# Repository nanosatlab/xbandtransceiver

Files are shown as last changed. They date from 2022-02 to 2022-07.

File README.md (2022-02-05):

# **Description**

The subsystem is designed as a generic X-band front-end subsystem. It will have to communicate with an On-Board-Computer (OBC) using UART protocol, be powered from the spacecraft’s 12 V power bus and have a PC/104 daughter board form factor. It also has to ensure a downlink data rate of at least 10 Mbps from 5º over the horizon at a 550 km LEO orbit, and with a bit-error-rate (BER) of 10^-5.

The subsystem is formed by:	SDR <-> Front-End <-> Antenna

The objective of this repository is to make accessible all the files related to the X-band transceiver, also called XCOMMS, which includes the hardware designs and all the necessary software of the subsystem as well as the different test boards that have been developed. This repository also includes the design of the required evaluatino boards that have been required for testing the subsystem.

# **Current state of the project**

At the moment, none of the PCB designs have been updated because they are pending to be translated from Altium to KiCad.
The project just includes the Front-End part.
The SDR and antenna parts are TBD. 

# **Project Tree Structure**

	XCOMMS
	├───Readme
	├───FrontEnd
	│   ├───Readme
	│   ├───HW
	│   │   ├───KiCad_Libraries
	│   │   ├───XCOMMS_Interface
	│   │   └───XCOMMS_RF
	│   └───SW
 	│	
	└───TesBoards
	    ├───PA_HMC952ALP5GE
	    │   ├───HW
	    │   └───SW
	    └───PLL_LMX2572
	    	├───Readme
		├───HW
		└───SW
		    ├───LMX2572
		    └───LMX2572_TICSPRO

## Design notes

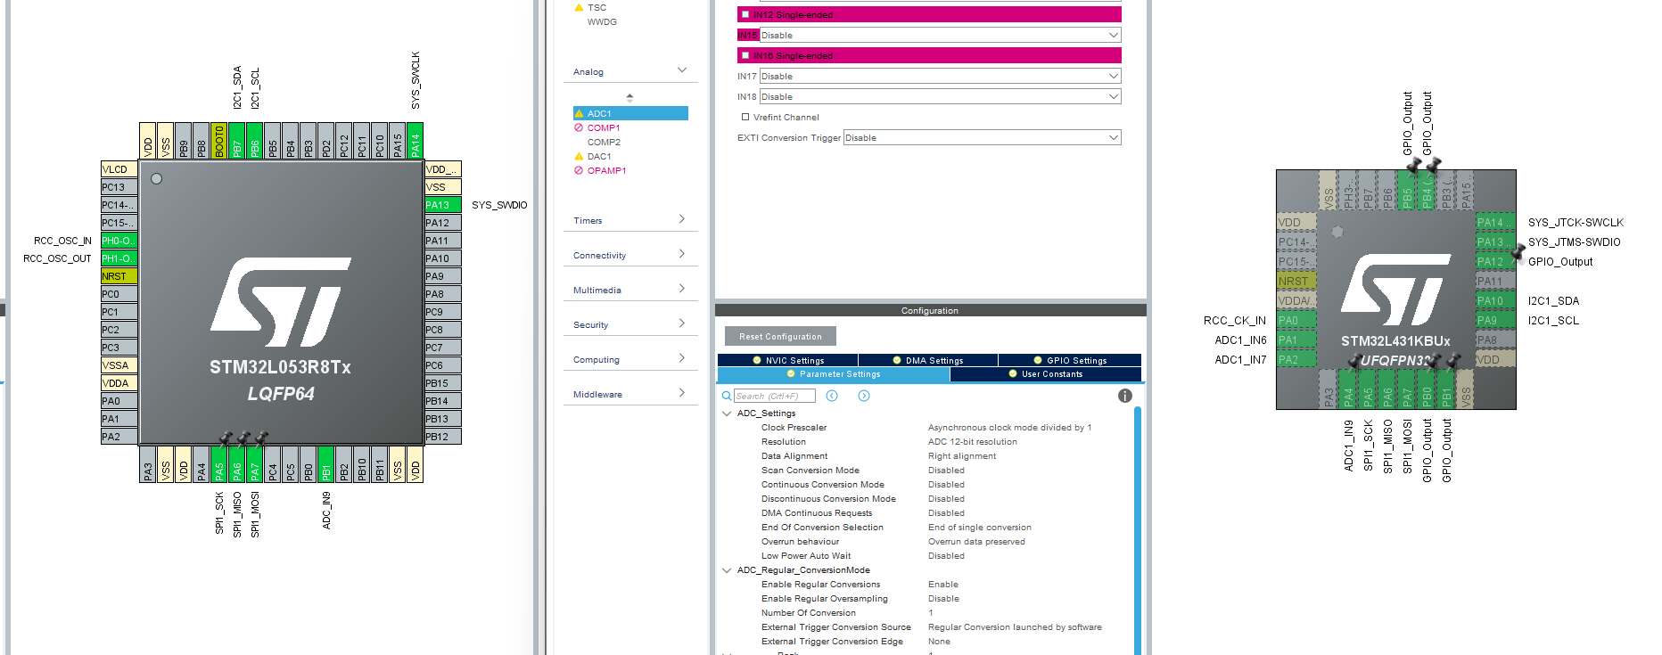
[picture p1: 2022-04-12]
FrontEnd/HW/XCOMMS_Interface/Captura de pantalla 2022-04-13 002548.png

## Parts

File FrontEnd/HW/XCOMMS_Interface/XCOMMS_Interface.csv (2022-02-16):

Source: | C:\Users\guill\Documents\GitHub\xbandtransceiver\FrontEnd\HW\XCOMMS_Interface\XCOMMS_Interface.kicad_sch
Date: | 16/2/2022 16:37:43
Tool: | Eeschema (6.0.1)
Generator: | C:\Program Files\KiCad\6.0\bin\scripting\plugins/bom_csv_grouped_by_value_with_fp.py
Component Count: | 92
Ref | Qnty | Value | Cmp name | Footprint | Description | Vendor
12V1, | 1 | MOLEX_52610271 | Picoblade_2x1_H | Connector_Molex:Molex_PicoBlade_53261-0271_1x02-1MP_P1.25mm_Horizontal
C1, | 1 | 4.7uF | C | Capacitor_SMD:C_0805_2012Metric | Unpolarized capacitor
C2, C5, C30, C31, C32, | 5 | 1uF | C | Capacitor_SMD:C_0603_1608Metric | Unpolarized capacitor
C3, C4, C6, C9, C12, C15, C16, C17, C18, C28, | 10 | 100nF | C | Capacitor_SMD:C_0603_1608Metric | Unpolarized capacitor
C7, C8, C10, C11, C13, C14, C19, C20, C21, C22, C23, C24, | 12 | 10uF | C | Capacitor_SMD:C_0805_2012Metric | Unpolarized capacitor
C25, C26, C27, | 3 | 100pF | C | Capacitor_SMD:C_0603_1608Metric | Unpolarized capacitor
C29, C33, C34, C35, C36, C37, C38, C39, C40, | 9 | 0.33uF | C | Capacitor_SMD:C_0603_1608Metric | Unpolarized capacitor
J1, | 1 | TFC-110-02-F-D-A-P-FR | TFC-110-T2 | GGS_Connectors:SAMTEC_TFC-110-02-F-D-A-P-FR
JTAG1, | 1 | MOLEX_532610471 | Picoblade_4x1_H | Connector_Molex:Molex_PicoBlade_53261-0471_1x04-1MP_P1.25mm_Horizontal
L1, L2, | 2 | 3.3uH | L | Inductor_SMD:L_Bourns_SRP5030T | Inductor
L3, | 1 | 2.2uH | L | Inductor_SMD:L_Coilcraft_XAL60xx_6.36x6.56mm | Inductor
R1, | 1 | 510 | R | Resistor_SMD:R_0603_1608Metric | Resistor
R2, | 1 | 169k | R | Resistor_SMD:R_0603_1608Metric | Resistor
R3, | 1 | 90.9k | R | Resistor_SMD:R_0603_1608Metric | Resistor
R4, R6, R8, R15, R17, R18, R21, | 7 | 20k | R | Resistor_SMD:R_0603_1608Metric | Resistor
R5, | 1 | 73.2k | R | Resistor_SMD:R_0603_1608Metric | Resistor
R7, | 1 | 45.3k | R | Resistor_SMD:R_0603_1608Metric | Resistor
R9, | 1 | 36.1k | R | Resistor_SMD:R_0603_1608Metric | Resistor
R10, R11, R12, R13, R16, R20, | 6 | 10k | R | Resistor_SMD:R_0603_1608Metric | Resistor
R14, | 1 | 0R | R | Resistor_SMD:R_0603_1608Metric | Resistor
R19, | 1 | 5k | R | Resistor_SMD:R_0603_1608Metric | Resistor
Rsense1, Rsense2, | 2 | 0R005 | R | Resistor_SMD:R_1206_3216Metric | Resistor
SCRW1, SCRW2, SCRW3, SCRW4, | 4 | MountingHole_Pad | MountingHole_Pad | MountingHole:MountingHole_3.2mm_M3_Pad_Via | Mounting Hole with connection
TP1, TP2, TP3, TP4, TP5, TP6, TP7, | 7 | TestPoint | TestPoint | TestPoint:TestPoint_Pad_D1.0mm | test point
U1, | 1 | STM32L431KBUx | STM32L431KBUx | Package_DFN_QFN:QFN-32-1EP_5x5mm_P0.5mm_EP3.45x3.45mm | ARM Cortex-M4 MCU, 128KB flash, 64KB RAM, 80MHz, 1.71-3.6V, 26 GPIO, UFQFPN-32
U2, U3, U4, | 3 | TPS56637 | TPS56637 | GGS_Power:TPS56637RPAR
U5, | 1 | TPS784 | TPS784 | Package_TO_SOT_SMD:SOT-23-5
U6, U9, U10, | 3 | MAX870EUK | MAX870 | Package_TO_SOT_SMD:SOT-23-5
U7, | 1 | INA290 | INA290 | GGS_Miscellaneous:SC70-5
U8, | 1 | AD5160 | AD1560 | Package_TO_SOT_SMD:SOT-23-8
UART1, | 1 | MOLEX_532610471 | Picoblade_4x1_H | Connector_Molex:Molex_PicoBlade_53261-0471_1x04-1MP_P1.25mm_Horizontal
Y1, | 1 | TCXO_ECS | TCXO_ECS | GGS_Miscellaneous:TCXO_ECS

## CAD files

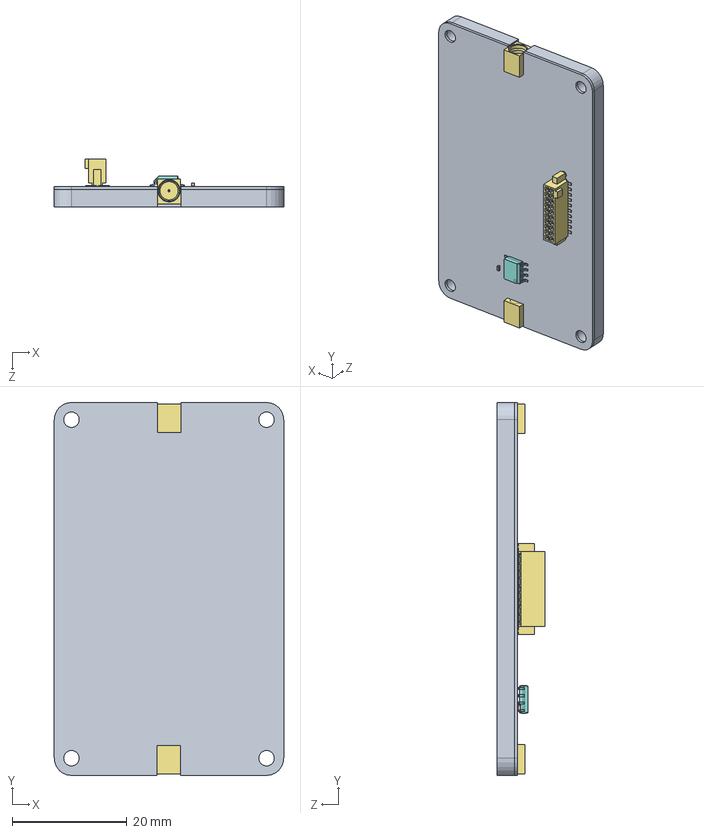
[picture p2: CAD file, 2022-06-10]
FrontEnd/HW/XCOMMS_Structure/XCOMMS_Assembly/XCOMMS_Assembly.SLDASM
40.0 x 65.0 x 8.35 mm
SOLID.step x 3
SOLID-0.step x 35
SOLID-1.step x 3
SOLID-2.step x 19
SOLID-3.step
SOLID-4.step x 2
SOLID-5.step
SOLID-6.step x 4
SOLID-7.step x 7
COMPOUND.step
COMPOUND-8.step
COMPOUND-9.step
SOLID-10.step
COMPOUND-11.step
COMPOUND-12.step
XCOMMS_RF PCB.step

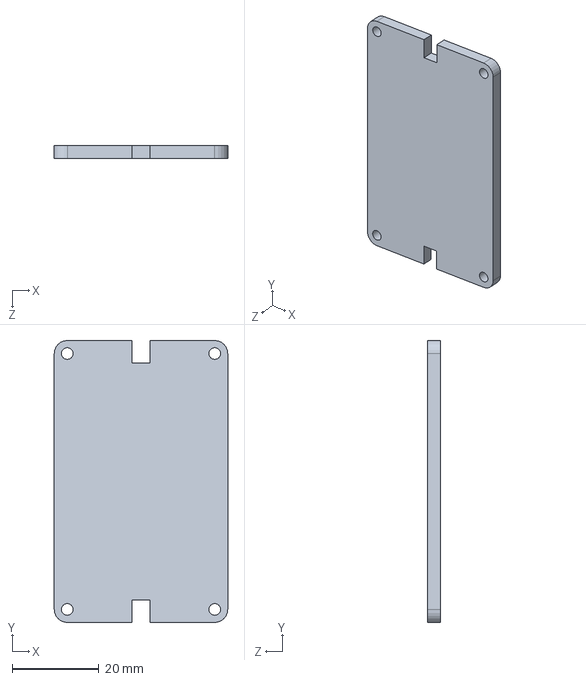
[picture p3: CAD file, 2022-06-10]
FrontEnd/HW/XCOMMS_Structure/XCOMMS_Assembly/Part17.SLDPRT
40.0 x 65.0 x 3.00 mm

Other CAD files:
FrontEnd/HW/XCOMMS_EGSE/XCOMMS_EGSE/XCOMMS_EGSE.dxf
FrontEnd/HW/XCOMMS_Structure/XCOMMS_RFshield/XCOMMS_RFshield.SLDPRT

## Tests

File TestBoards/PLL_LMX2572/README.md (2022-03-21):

# **Description**

This folder includes the [LMX2572](https://www.ti.com/lit/ds/symlink/lmx2572.pdf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) PLL evaluation board related files. It has been designed in orther to test signal reference generation from a TCXO of 25 MHz that is attached to the evaluation board. If another clock reference is desired, it is necessary to desolder the 25 MHz TCXO reference and instead the OSCin pin can be used.

# **How to use the test board**

To use the LMX2572 evaluation board you will need a Nucleo-L476RG developement board and the [STM32CubeIDE](https://www.st.com/en/development-tools/stm32cubeide.html). It can be programmed either using the oficial developement program [TICS Pro](https://www.ti.com/tool/TICSPRO-SW) from TexasInstruments or using the custom created library.

## Connections

The LMX2572 evaluation board is powered by a single 3.3 V line and can be connected either to the Nucleo-L476RG supply or to an external power supply. It is important to consider the grounding connections. If the computer connected to the Nucleo board is connected to the power line, an additional connection should be added between the ground of the LMX2572 evaluation board and the Nucleo board to make sure that the ground planes are at the same level. If not done, malfunction of the LMX2572 evaluation board may occur.

Nominal current consumption when not powered is around 34 mA, and when powered around 80-90 mA.   

If the RF output is connected to an SA, consider putting at least a 30 dB attenuator in between.

The LMX2572 uses SPI in order to be controlled. The code has been written using the hspi1 peripheral of the Nucleo-L476RG board with the GPIOA9 pin as the CSB:



Connections on the Nucleo-L476RG for dummies are (me): green - D5, blak - D11, orange - D12, yellow - D13

## Programming with TICS PRO

You can program the LMX2572 evaluation board using the Texas Instruments GUI following this procedure:
  1. Configure the LMX2572 as deisred using TICS PRO software (note the limitations of the evaluation board)
  2. Export the Register Map as a .txt
  3. Copy the .txt content into an Excel document, it should create two columns: one with the register name and the other with the content 
  4. Add a third column full of commas (,) until the last register not included
  5. Copy the second and third column and replace the contents of lmx2572_configs.h
  6. Compile code and execute

## Programming with custom library 
**This part is not recomended to be used yet because is still in developement phase.**

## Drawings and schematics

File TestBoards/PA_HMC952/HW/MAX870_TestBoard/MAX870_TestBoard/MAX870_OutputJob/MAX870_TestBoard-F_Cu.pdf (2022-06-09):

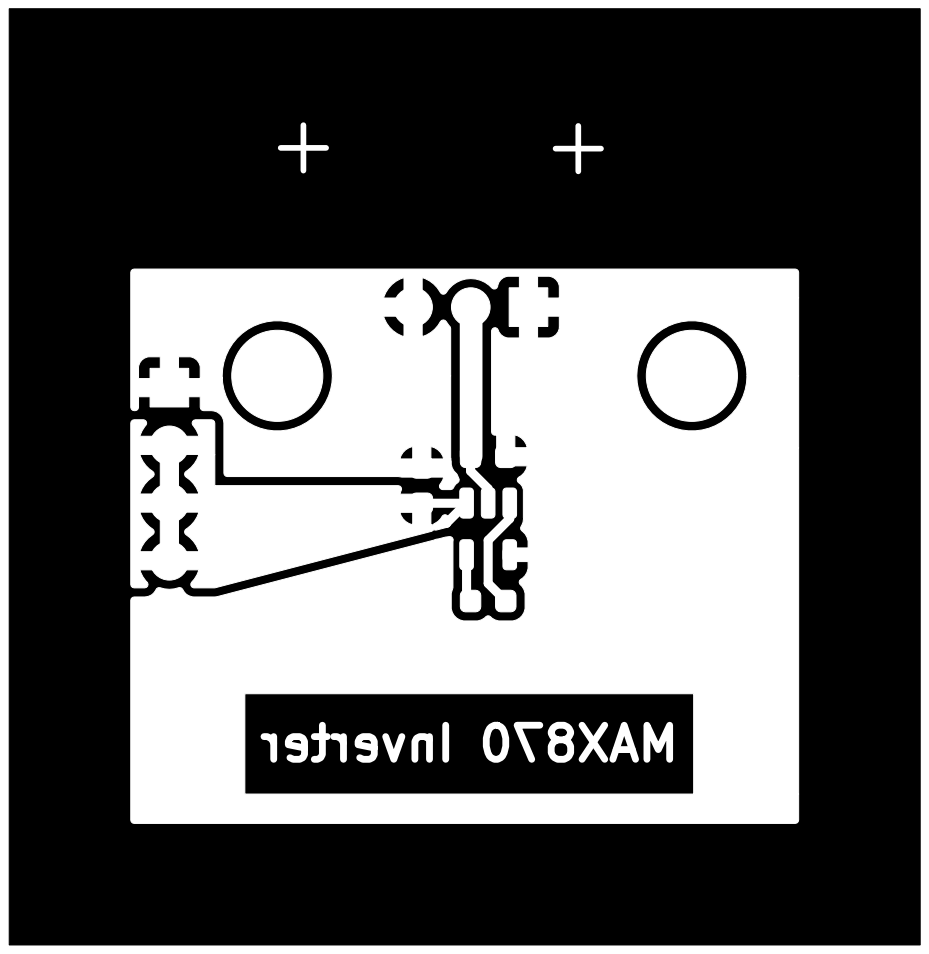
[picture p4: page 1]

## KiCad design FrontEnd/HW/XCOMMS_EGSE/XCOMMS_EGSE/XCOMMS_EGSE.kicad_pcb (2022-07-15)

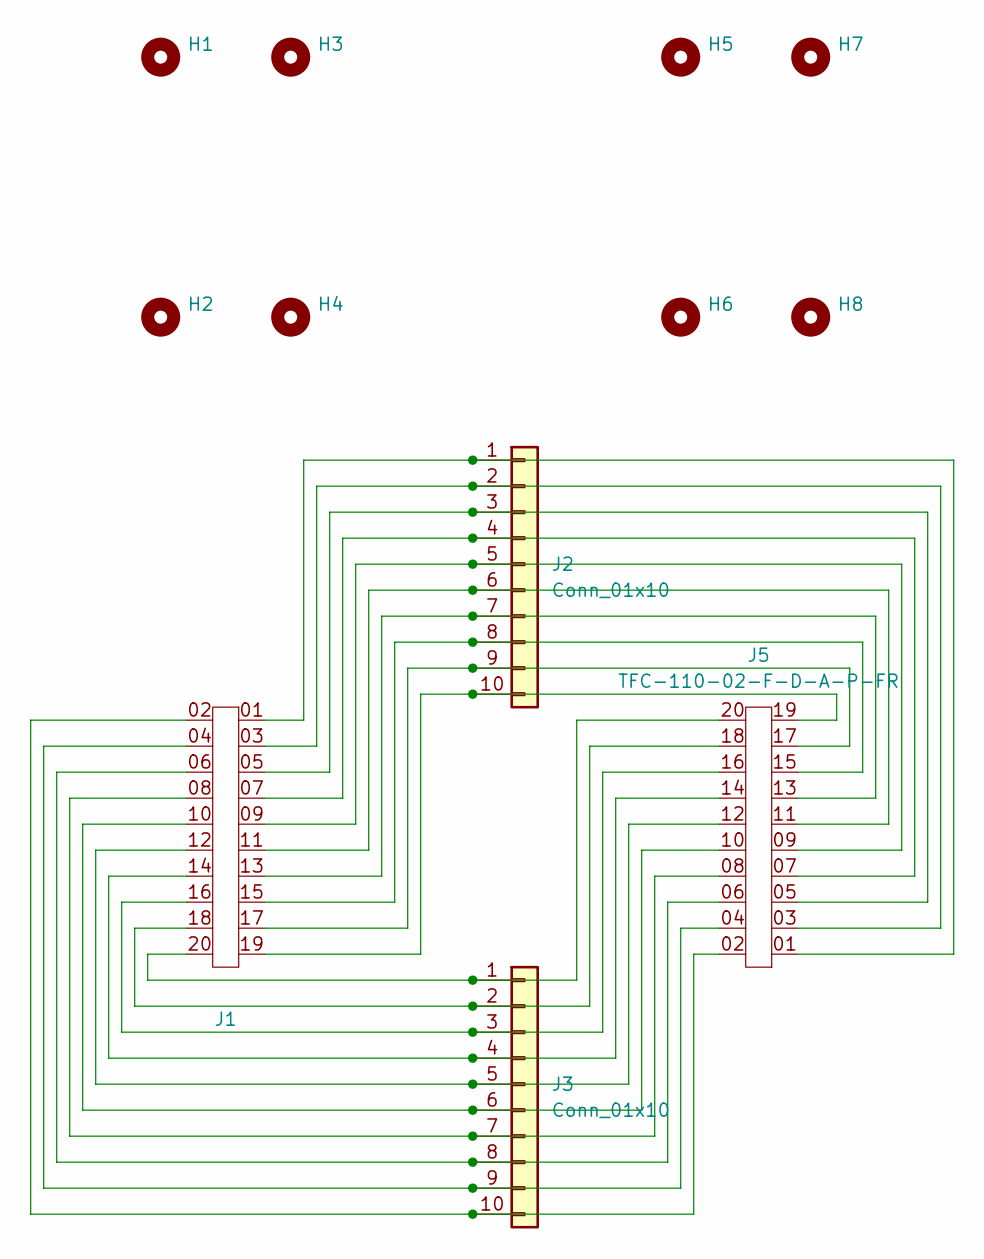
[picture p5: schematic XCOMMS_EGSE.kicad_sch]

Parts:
H1, H2, H3, H4, H5, H6, H7, H8: MountingHole; MountingHole_2.7mm_M2.5
J1: TFC-110-02-F-D-A-P-FR; SAMTEC_TFC-110-02-F-D-A-P-FR
J2, J3: Conn_01x10; PinSocket_1x10_P2.54mm_Vertical
J5: TFC-110-02-F-D-A-P-FR; SAMTEC_SFC-110-T2-F-D-A-TR

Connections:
unnamed: J1.01, J2.1, J5.01
unnamed: J1.02, J3.10, J5.02
unnamed: J1.03, J2.2, J5.03
unnamed: J1.04, J3.9, J5.04
unnamed: J1.05, J2.3, J5.05
unnamed: J1.06, J3.8, J5.06
unnamed: J1.07, J2.4, J5.07
unnamed: J1.08, J3.7, J5.08
unnamed: J1.09, J2.5, J5.09
unnamed: J1.10, J3.6, J5.10
unnamed: J1.11, J2.6, J5.11
unnamed: J1.12, J3.5, J5.12
unnamed: J1.13, J2.7, J5.13
unnamed: J1.14, J3.4, J5.14
unnamed: J1.15, J2.8, J5.15
unnamed: J1.16, J3.3, J5.16
unnamed: J1.17, J2.9, J5.17
unnamed: J1.18, J3.2, J5.18
unnamed: J1.19, J2.10, J5.19
unnamed: J1.20, J3.1, J5.20

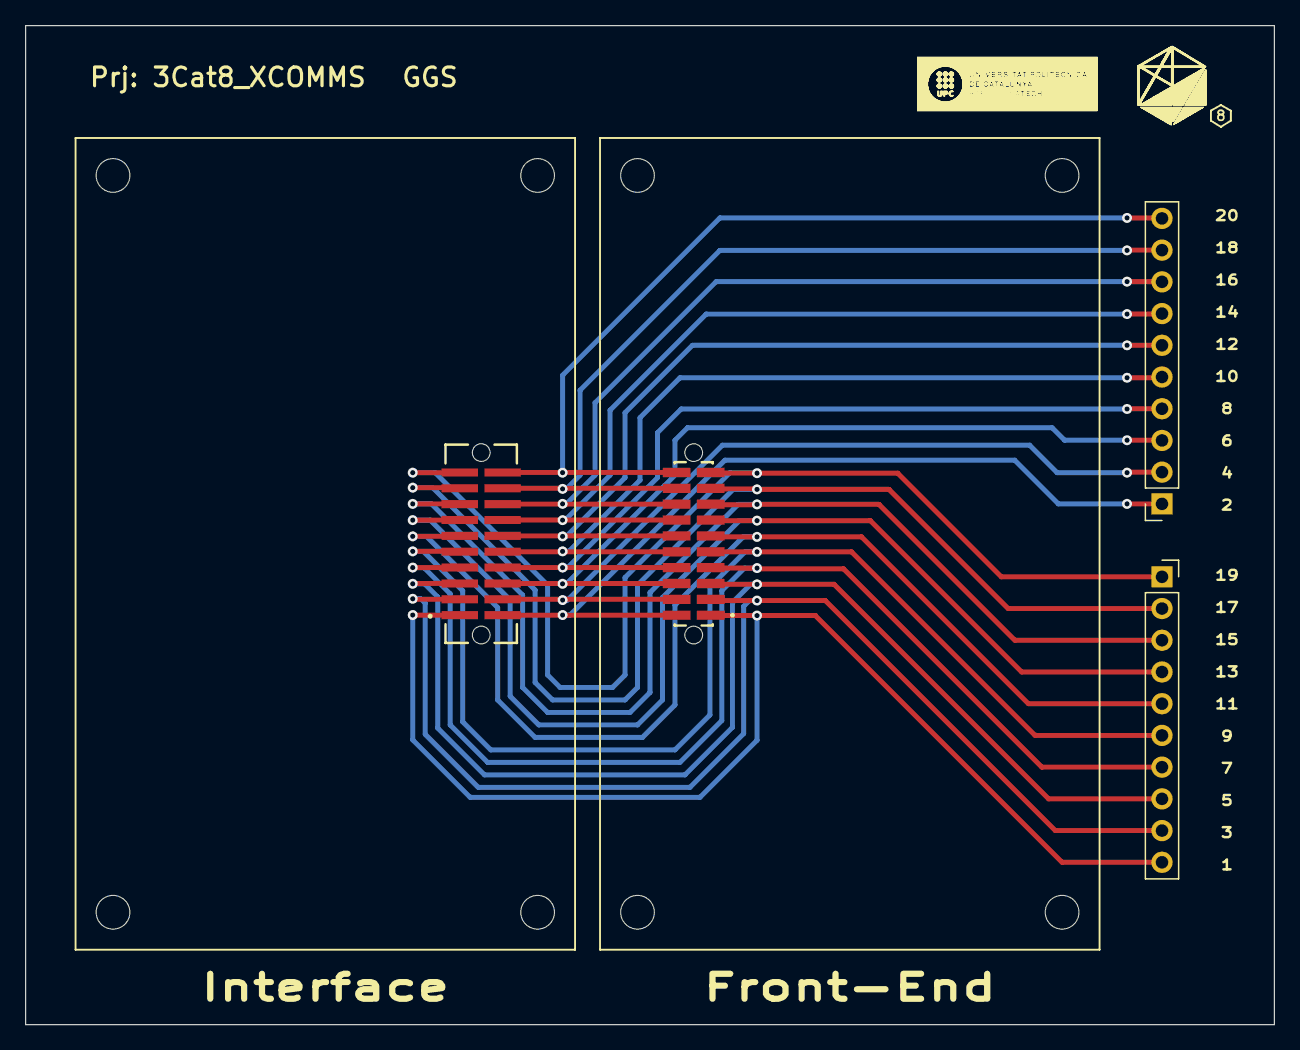
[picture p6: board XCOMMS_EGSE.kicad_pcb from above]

Board: 2 copper layers, 100.0 x 80.0 mm, 12 parts (0 on the bottom side), 20 nets.

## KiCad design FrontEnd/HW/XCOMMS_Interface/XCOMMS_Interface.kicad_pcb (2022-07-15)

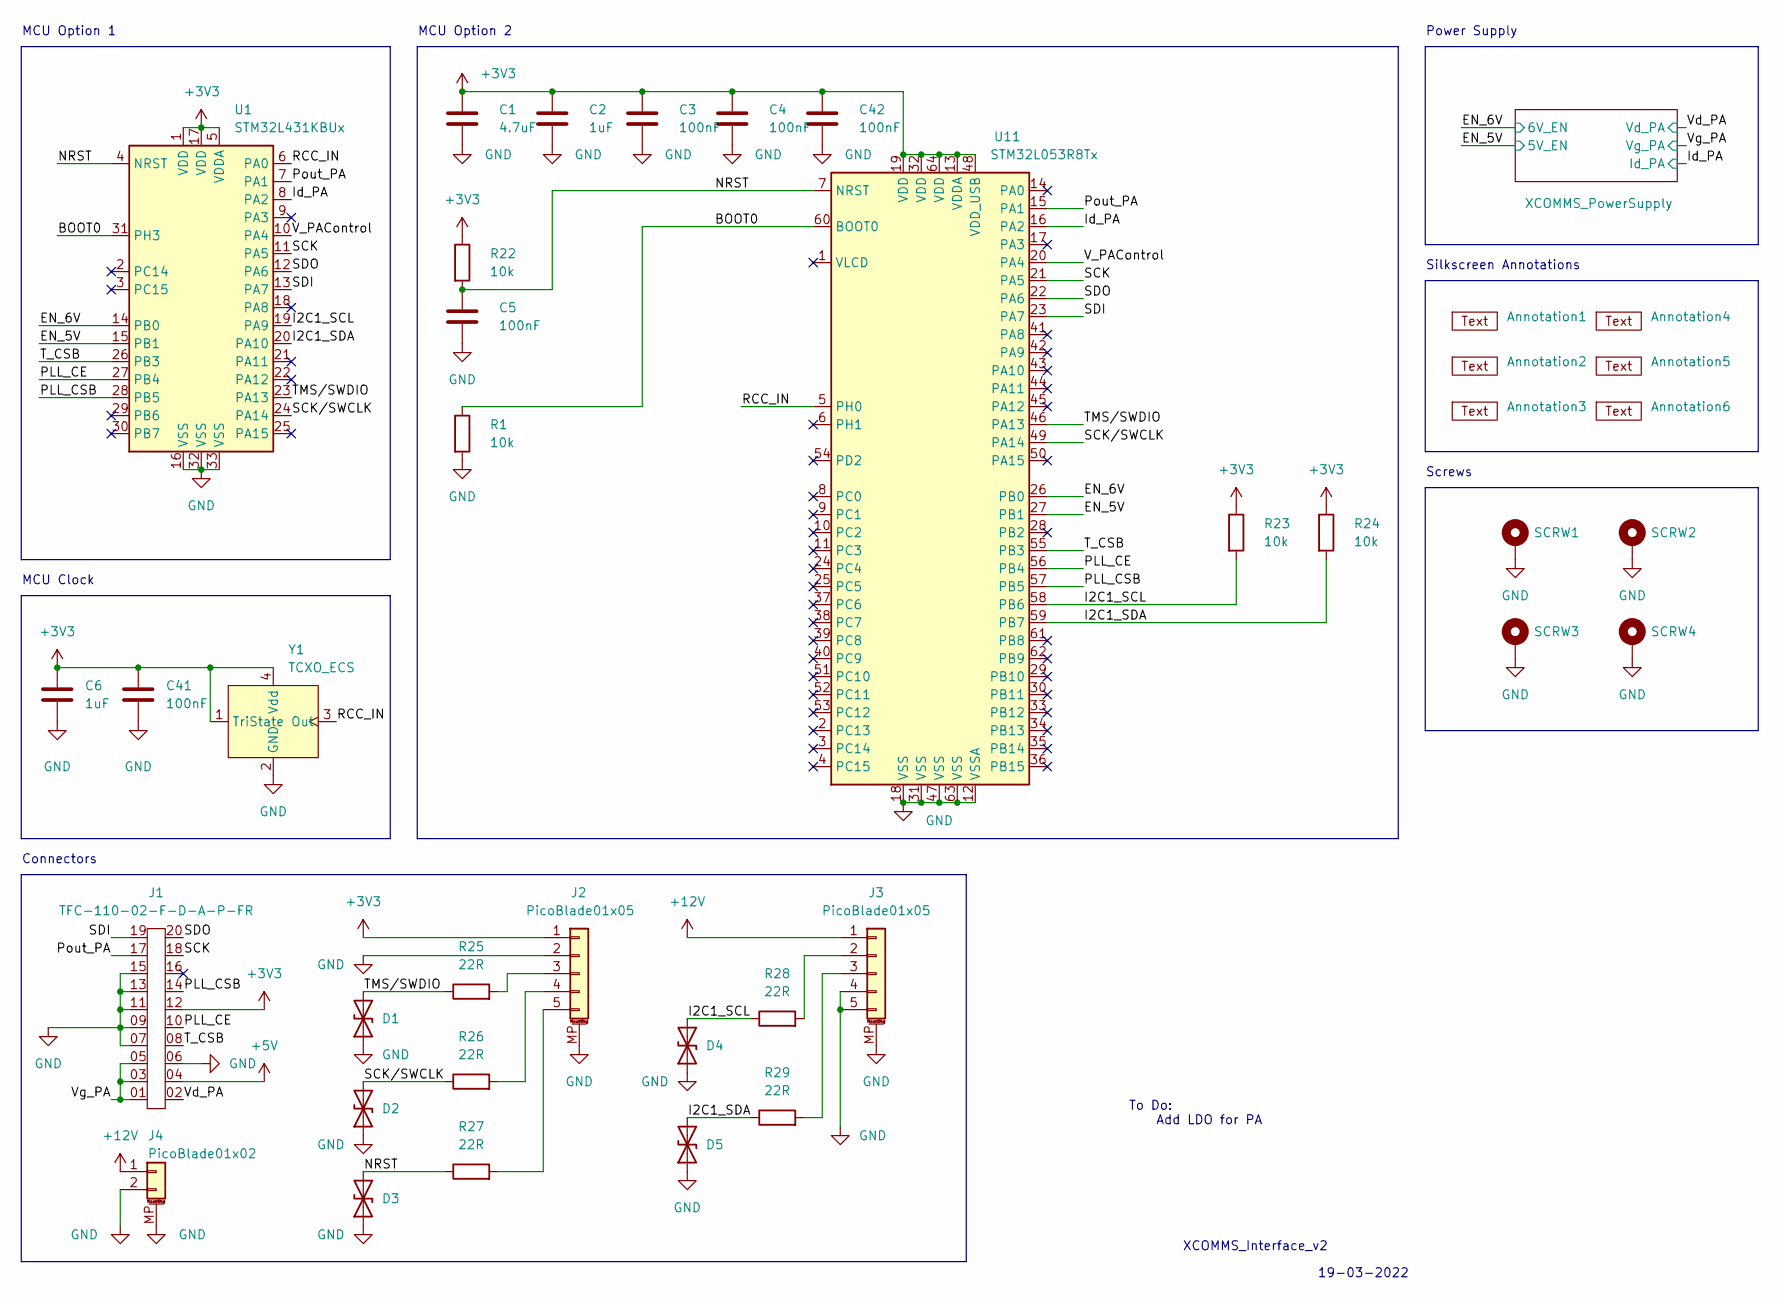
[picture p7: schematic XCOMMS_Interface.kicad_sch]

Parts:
Annotation1: Silkscreen_Annotation; Bike
Annotation2: Silkscreen_Annotation; GGS
Annotation3: Silkscreen_Annotation; NSL
Annotation4: Silkscreen_Annotation; Prj
Annotation5: Silkscreen_Annotation; Rev
Annotation6: Silkscreen_Annotation; UPC
C1: 4.7uF; C_0603_1608Metric
C2, C6: 1uF; C_0603_1608Metric
C3, C4, C5, C41, C42: 100nF; C_0603_1608Metric
D1, D2, D3, D4, D5: SZESD9X3.3ST5G; D_SOD-923; MPN SZESD9X3.3ST5G
J1: TFC-110-02-F-D-A-P-FR; SAMTEC_TFC-110-02-F-D-A-P-FR
J2, J3: PicoBlade01x05; Molex_PicoBlade_53261-0571_1x05-1MP_P1.25mm_Horizontal
J4: PicoBlade01x02; Molex_PicoBlade_53261-0271_1x02-1MP_P1.25mm_Horizontal
R1, R22, R23, R24: 10k; R_0603_1608Metric
R25, R26, R27, R28, R29: 22R; R_0603_1608Metric
SCRW1, SCRW2, SCRW3, SCRW4: MountingHole_Pad; MountingHole_2.7mm_M2.5_Pad
U1: STM32L431KBUx; QFN-32-1EP_5x5mm_P0.5mm_EP3.45x3.45mm
U11: STM32L053R8Tx; LQFP-64_10x10mm_P0.5mm
Y1: TCXO_ECS

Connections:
+3V3: C1.1, C2.1, C3.1, C4.1, C6.1, C41.1, C42.1, J1.12, J2.1, R22.1, R23.1, R24.1, U1.1 (VDD), U1.5 (VDDA), U1.17 (VDD), U11.13 (VDDA), U11.19 (VDD), U11.32 (VDD), U11.48 (VDD_USB), U11.64 (VDD), Y1.1 (TriState), Y1.4 (Vdd); also elsewhere on the board
+5V: J1.04; also elsewhere on the board
+12V: J3.1, J4.1; also elsewhere on the board
/BOOT0: R1.1, U1.31 (PH3), U11.60 (BOOT0)
/EN_5V: U1.15 (PB1), U11.27 (PB1); also elsewhere on the board
/EN_6V: U1.14 (PB0), U11.26 (PB0); also elsewhere on the board
/I2C1_SCL: D4.2 (A2), R23.2, R28.1, U1.19 (PA9), U11.58 (PB6)
/I2C1_SDA: D5.2 (A2), R24.2, R29.1, U1.20 (PA10), U11.59 (PB7)
/Id_PA: U1.8 (PA2), U11.16 (PA2); also elsewhere on the board
/NRST: C5.1, D3.2 (A2), R22.2, R27.1, U1.4 (NRST), U11.7 (NRST)
/PLL_CE: J1.10, U1.27 (PB4), U11.56 (PB4)
/PLL_CSB: J1.14, U1.28 (PB5), U11.57 (PB5)
/Pout_PA: J1.17, U1.7 (PA1), U11.15 (PA1)
/RCC_IN: U1.6 (PA0), U11.5 (PH0), Y1.3 (Out)
/SCK: J1.18, U1.11 (PA5), U11.21 (PA5)
/SCK/SWCLK: D2.2 (A2), R26.1, U1.24 (PA14), U11.49 (PA14)
/SDI: J1.19, U1.13 (PA7), U11.23 (PA7)
/SDO: J1.20, U1.12 (PA6), U11.22 (PA6)
/TMS/SWDIO: D1.2 (A2), R25.1, U1.23 (PA13), U11.46 (PA13)
/T_CSB: J1.08, U1.26 (PB3), U11.55 (PB3)
/V_PAControl: U1.10 (PA4), U11.20 (PA4)
/Vd_PA: J1.02; also elsewhere on the board
/Vg_PA: J1.01, J1.03, J1.05; also elsewhere on the board
GND: C1.2, C2.2, C3.2, C4.2, C5.2, C6.2, C41.2, C42.2, D1.1 (A1), D2.1 (A1), D3.1 (A1), D4.1 (A1), D5.1 (A1), J1.06, J1.07, J1.09, J1.11, J1.13, J1.15, J2.2, J2.MP (MountPin), J3.4, J3.5, J3.MP (MountPin), J4.2, J4.MP (MountPin), R1.2, SCRW1.1, SCRW2.1, SCRW3.1, SCRW4.1, U1.16 (VSS), U1.32 (VSS), U1.33 (VSS), U11.12 (VSSA), U11.18 (VSS), U11.31 (VSS), U11.47 (VSS), U11.63 (VSS), Y1.2 (GND); also elsewhere on the board
unnamed: J2.3, R25.2
unnamed: J2.4, R26.2
unnamed: J2.5, R27.2
unnamed: J3.2, R28.2
unnamed: J3.3, R29.2

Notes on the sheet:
Silkscreen Annotations
MCU Option 2
Power Supply
MCU Clock
MCU Option 1
XCOMMS_Interface_v2
Connectors
19-03-2022
Screws
To Do: Add LDO for PA

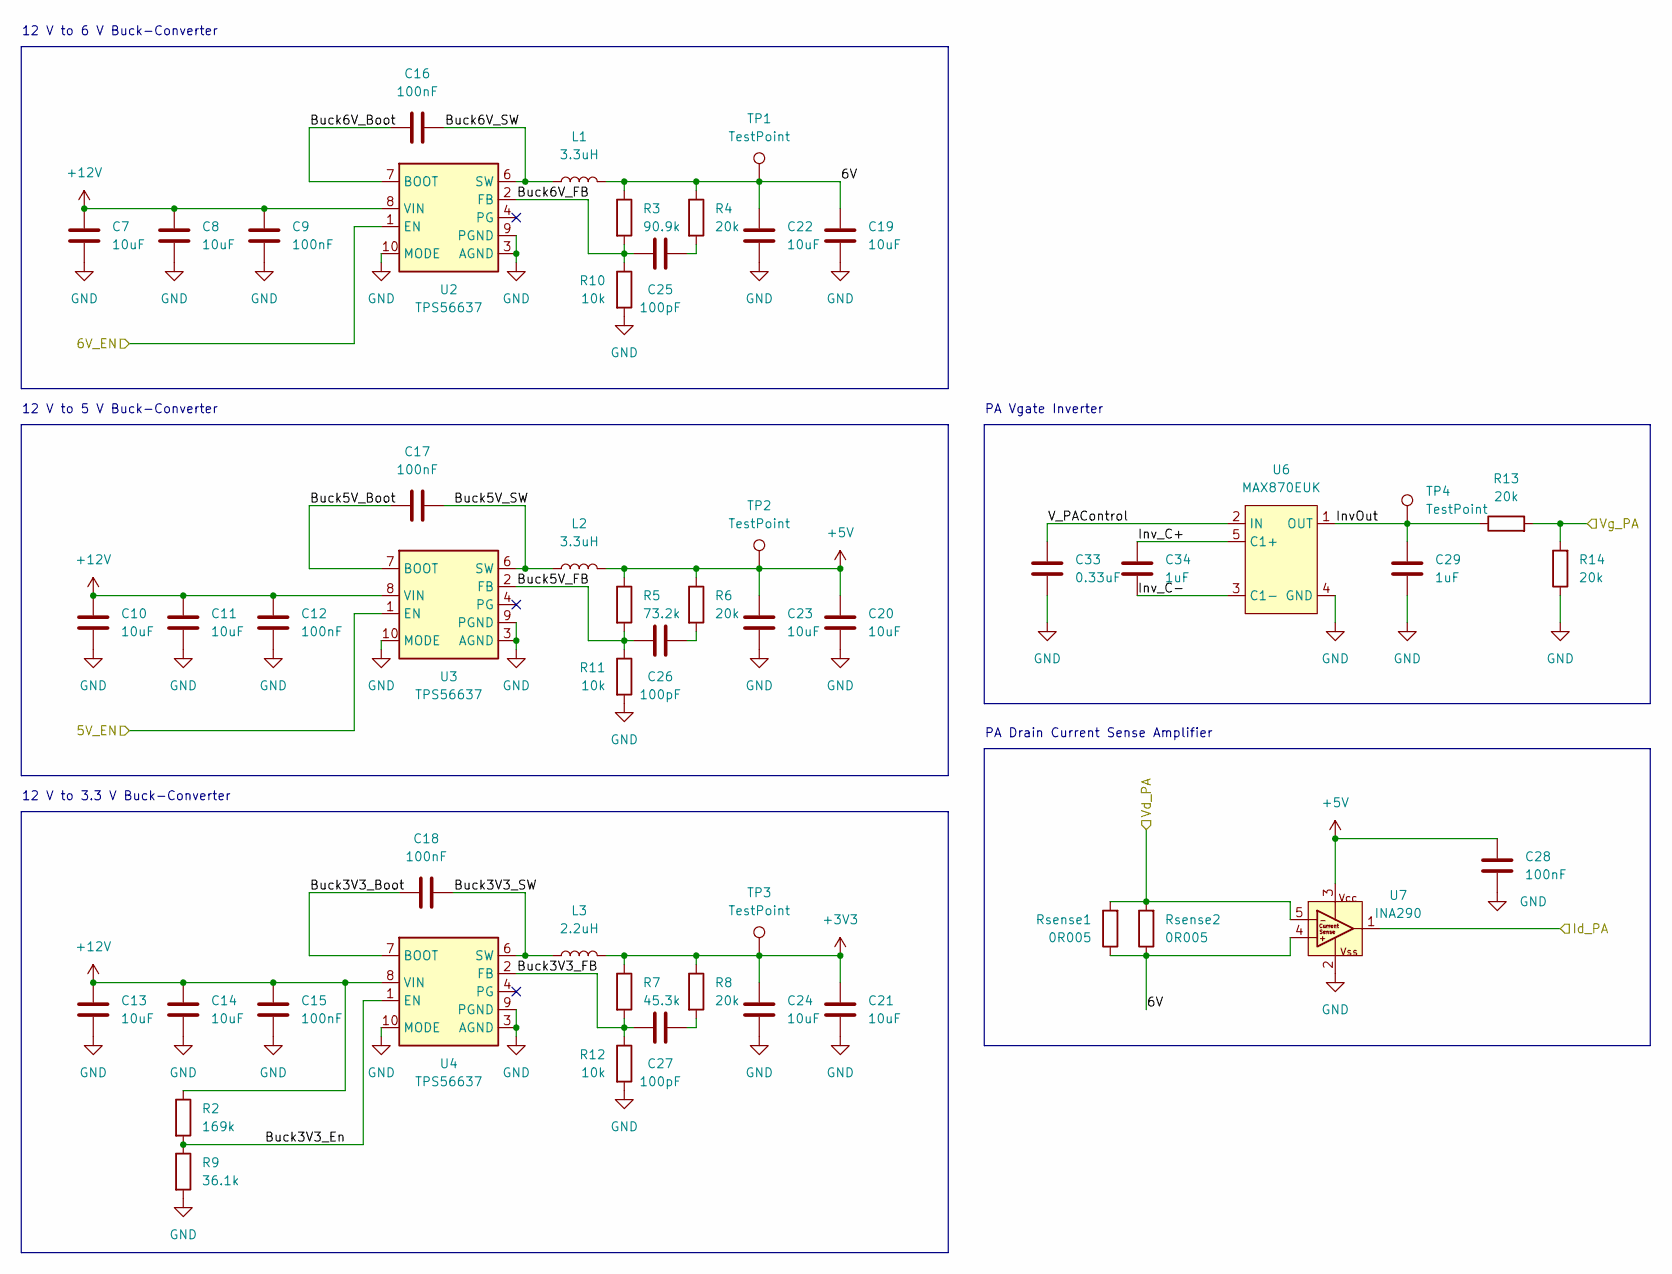
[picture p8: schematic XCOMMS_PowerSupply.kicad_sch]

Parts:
C7, C8, C10, C11, C13, C14, C19, C20, C21, C22, C23, C24: 10uF; C_0603_1608Metric
C9, C12, C15, C16, C17, C18, C28: 100nF; C_0603_1608Metric
C25, C26, C27: 100pF; C_0603_1608Metric
C29, C34: 1uF; C_0603_1608Metric
C33: 0.33uF; C_0603_1608Metric
L1, L2: 3.3uH; L_Bourns_SRP5030T
L3: 2.2uH; L_Coilcraft_XAL60xx_6.36x6.56mm
R2: 169k; R_0603_1608Metric
R3: 90.9k; R_0603_1608Metric
R4, R6, R8, R13, R14: 20k; R_0603_1608Metric
R5: 73.2k; R_0603_1608Metric
R7: 45.3k; R_0603_1608Metric
R9: 36.1k; R_0603_1608Metric
R10, R11, R12: 10k; R_0603_1608Metric
Rsense1, Rsense2: 0R005; R_1206_3216Metric
TP1, TP2, TP3, TP4: TestPoint; TestPoint_Pad_D1.0mm
U2, U3, U4: TPS56637; TPS56637RPAR
U6: MAX870EUK; SOT-23-5
U7: INA290; SC70-5

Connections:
+3V3: C21.1, C24.1, L3.2, R7.1, R8.1, TP3.1; also elsewhere on the board
+5V: C20.1, C23.1, C28.2, L2.2, R5.1, R6.1, TP2.1, U7.3 (VCC); also elsewhere on the board
+12V: C7.1, C8.1, C9.1, C10.1, C11.1, C12.1, C13.1, C14.1, C15.1, R2.1, U2.8 (VIN), U3.8 (VIN), U4.8 (VIN); also elsewhere on the board
/EN_5V: U3.1 (EN); also elsewhere on the board
/EN_6V: U2.1 (EN); also elsewhere on the board
/Id_PA: U7.1 (OUT); also elsewhere on the board
/Vd_PA: Rsense1.2, Rsense2.2, U7.5 (IN-); also elsewhere on the board
/Vg_PA: R13.2, R14.2; also elsewhere on the board
/XCOMMS_PowerSupply/6V: C19.1, C22.1, L1.2, R3.1, R4.1, Rsense1.1, Rsense2.1, TP1.1, U7.4 (IN+)
/XCOMMS_PowerSupply/Buck3V3_Boot: C18.1, U4.7 (BOOT)
/XCOMMS_PowerSupply/Buck3V3_En: R2.2, R9.1, U4.1 (EN)
/XCOMMS_PowerSupply/Buck3V3_FB: C27.1, R7.2, R12.1, U4.2 (FB)
/XCOMMS_PowerSupply/Buck3V3_SW: C18.2, L3.1, U4.6 (SW)
/XCOMMS_PowerSupply/Buck5V_Boot: C17.1, U3.7 (BOOT)
/XCOMMS_PowerSupply/Buck5V_FB: C26.1, R5.2, R11.1, U3.2 (FB)
/XCOMMS_PowerSupply/Buck5V_SW: C17.2, L2.1, U3.6 (SW)
/XCOMMS_PowerSupply/Buck6V_Boot: C16.1, U2.7 (BOOT)
/XCOMMS_PowerSupply/Buck6V_FB: C25.1, R3.2, R10.1, U2.2 (FB)
/XCOMMS_PowerSupply/Buck6V_SW: C16.2, L1.1, U2.6 (SW)
/XCOMMS_PowerSupply/InvOut: C29.2, R13.1, TP4.1, U6.1 (OUT)
/XCOMMS_PowerSupply/Inv_C+: C34.2, U6.5 (C1+)
/XCOMMS_PowerSupply/Inv_C-: C34.1, U6.3 (C1-)
/XCOMMS_PowerSupply/V_PAControl: C33.2, U6.2 (IN)
GND: C7.2, C8.2, C9.2, C10.2, C11.2, C12.2, C13.2, C14.2, C15.2, C19.2, C20.2, C21.2, C22.2, C23.2, C24.2, C28.1, C29.1, C33.1, R9.2, R10.2, R11.2, R12.2, R14.1, U2.3 (AGND), U2.9 (PGND), U2.10 (MODE), U3.3 (AGND), U3.9 (PGND), U3.10 (MODE), U4.3 (AGND), U4.9 (PGND), U4.10 (MODE), U6.4 (GND), U7.2 (VSS); also elsewhere on the board
unnamed: C25.2, R4.2
unnamed: C26.2, R6.2
unnamed: C27.2, R8.2

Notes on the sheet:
12 V to 6 V Buck-Converter
12 V to 3.3 V Buck-Converter
PA Vgate Inverter
12 V to 5 V Buck-Converter
PA Drain Current Sense Amplifier

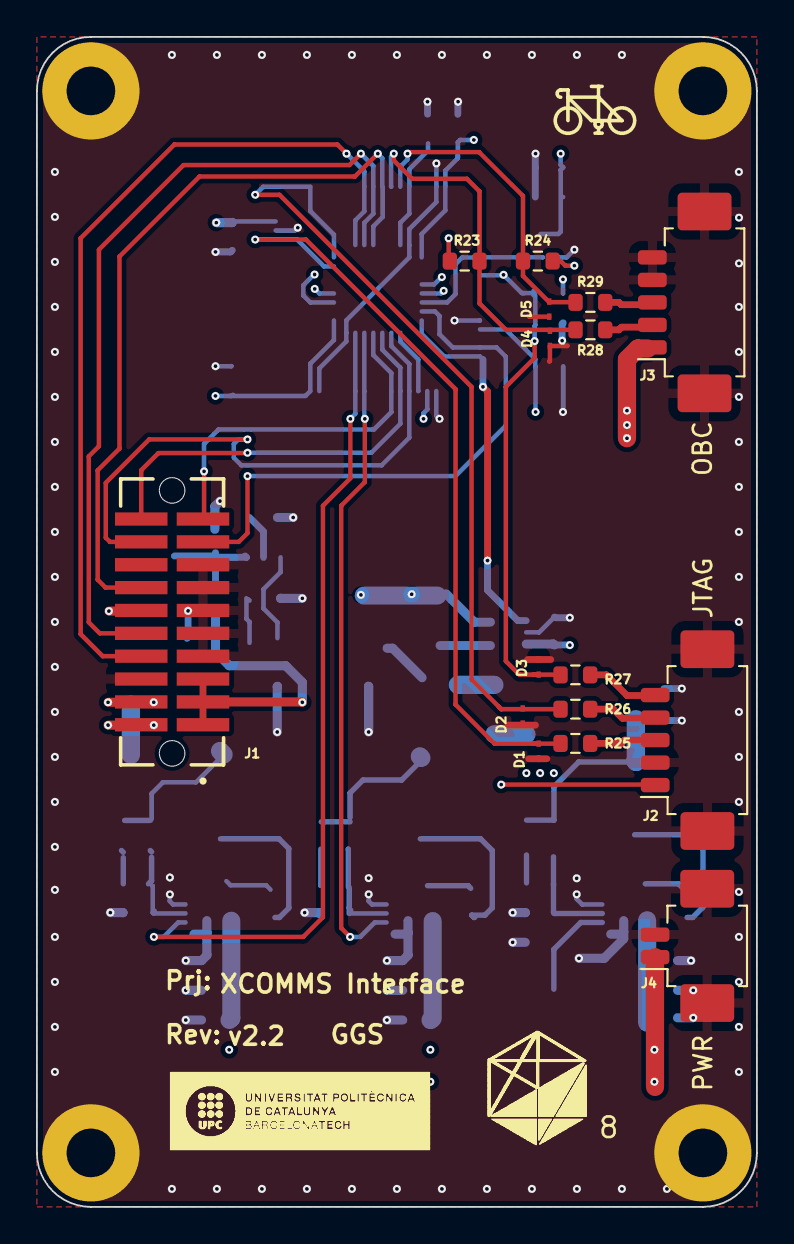
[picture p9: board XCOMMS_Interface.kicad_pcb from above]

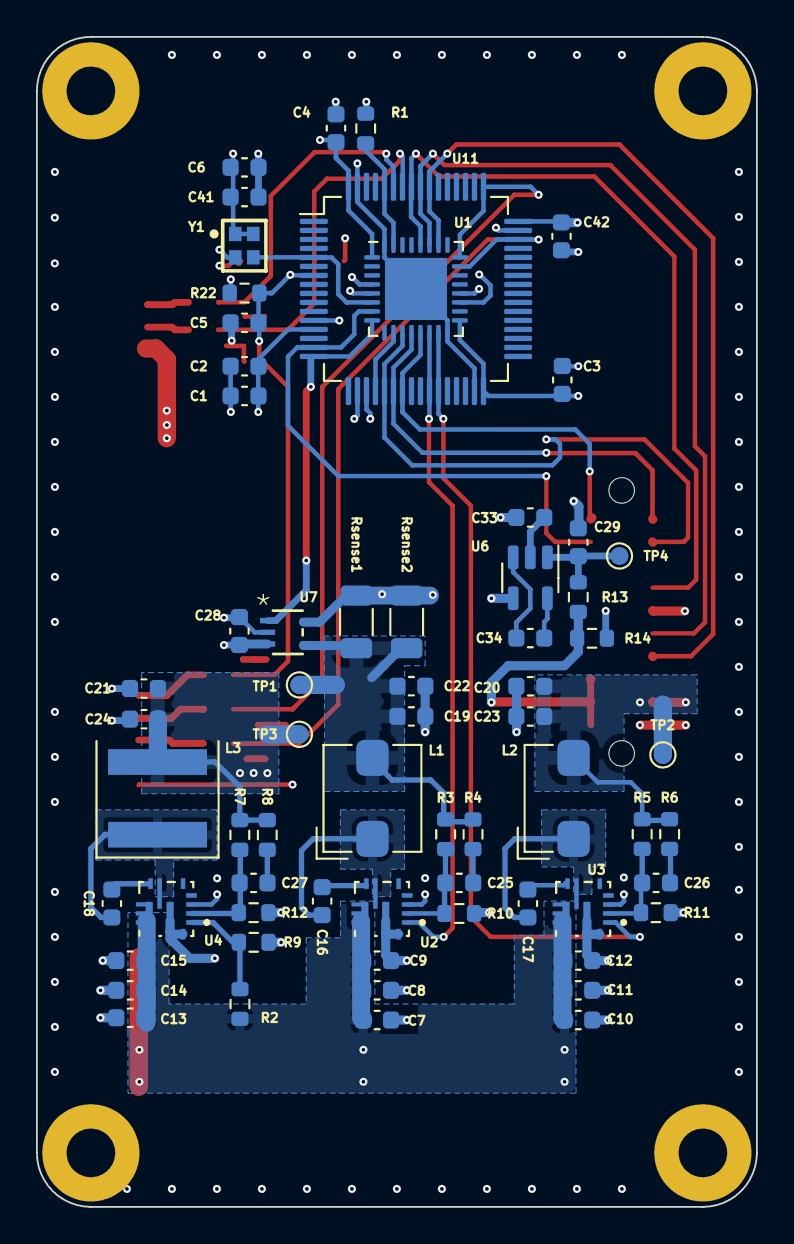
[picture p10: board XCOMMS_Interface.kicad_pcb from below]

Board: 4 copper layers, 40.0 x 65.0 mm, 91 parts (65 on the bottom side), 47 nets.

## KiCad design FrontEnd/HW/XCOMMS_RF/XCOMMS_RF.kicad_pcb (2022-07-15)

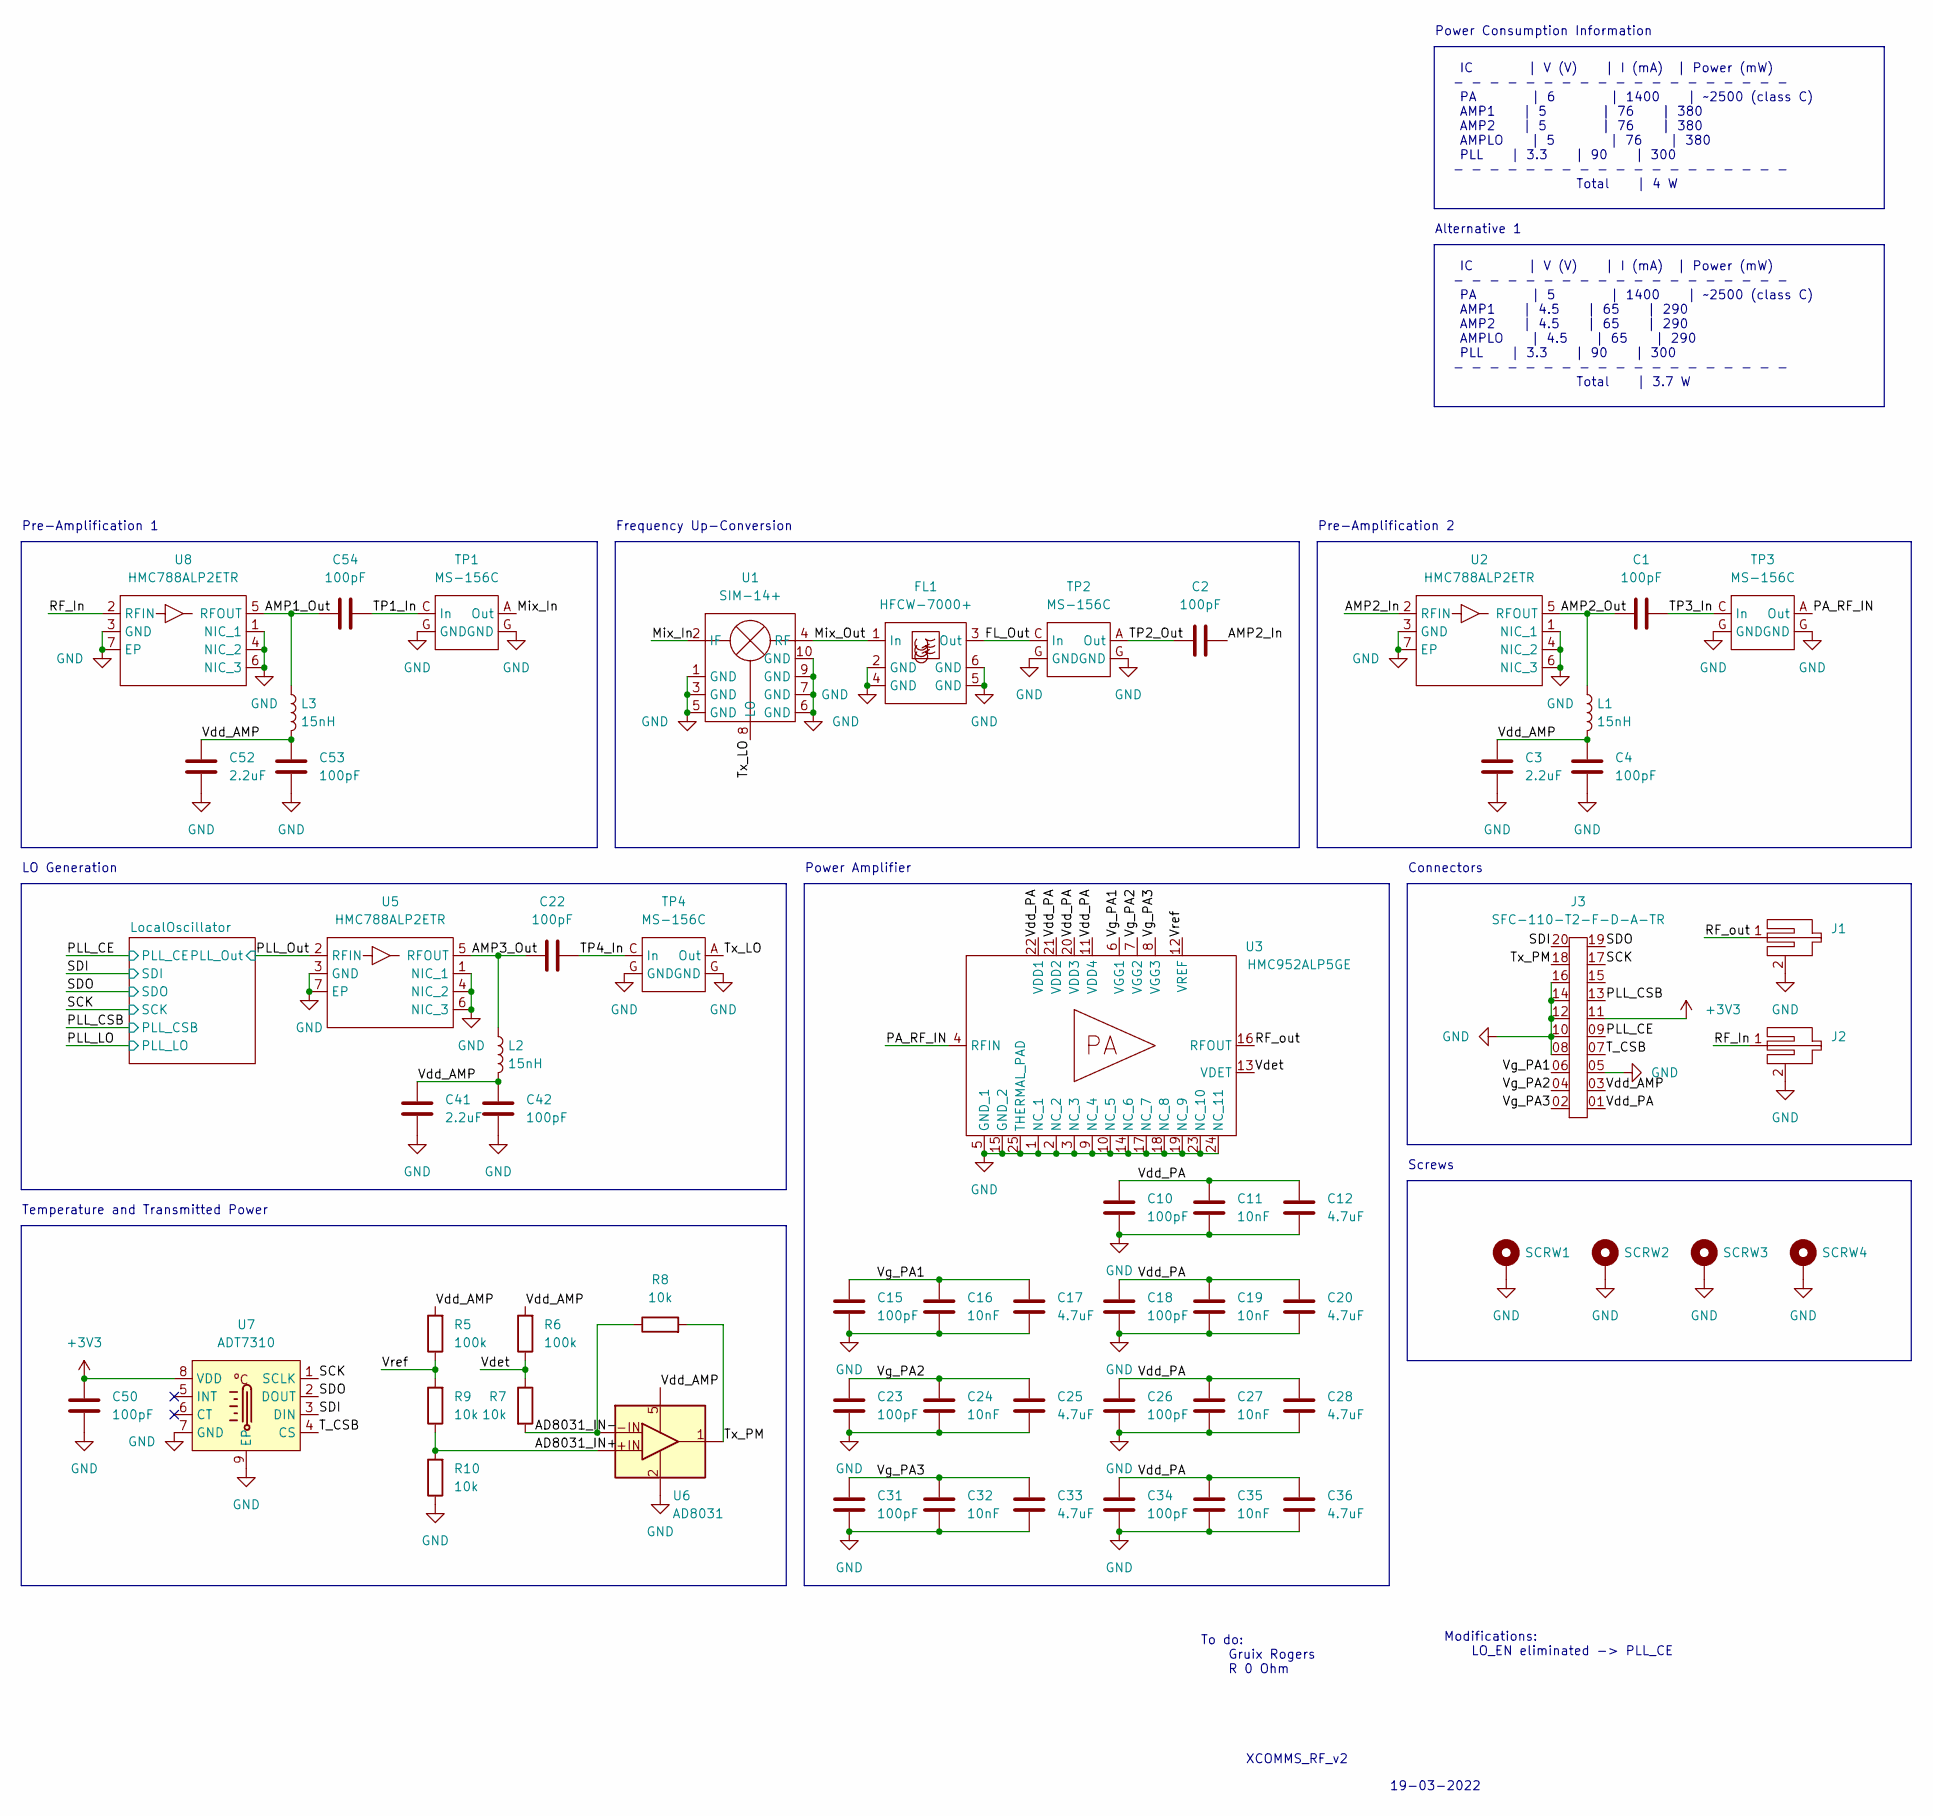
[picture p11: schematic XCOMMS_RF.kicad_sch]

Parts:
C1, C2, C4, C10, C15, C18, C22, C23, C26, C31, C34, C42, C50, C53, C54: 100pF; C_0402_1005Metric
C3, C41, C52: 2.2uF; C_0603_1608Metric
C11, C16, C19, C24, C27, C32, C35: 10nF; C_0603_1608Metric
C12, C17, C20, C25, C28, C33, C36: 4.7uF; C_0603_1608Metric
FL1: HFCW-7000+; JC0603C
J1, J2: SMP-MSLD-PCE-5T
J3: SFC-110-T2-F-D-A-TR; SAMTEC_SFC-110-T2-F-D-A-TR
L1, L2, L3: 15nH; L_0603_1608Metric
R5, R6: 100k; R_0603_1608Metric
R7, R8, R9, R10: 10k; R_0603_1608Metric
SCRW1, SCRW2, SCRW3, SCRW4: MountingHole_Pad; MountingHole_2.7mm_M2.5_ISO14580_Pad
TP1, TP2, TP3, TP4: MS-156C; CoaxialSwitch_Hirose_MS-156C3_Horizontal
U1: SIM-14+; SIM24MH
U2, U5, U8: HMC788ALP2ETR; SON65P200X200X90-7N-D; Mouser Part Number 584-HMC788ALP2ETR
U3: HMC952ALP5GE; QFN65P500X500X100-25N-D; Mouser Part Number 584-HMC952ALP5GE
U6: AD8031; SOT-23-5; MANUFACTURER_PART_NUMBER AD8031ARTZ-REEL7
U7: ADT7310; SOIC-8-1EP_3.9x4.9mm_P1.27mm_EP2.41x3.81mm

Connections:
+3V3: C50.2, J3.11, U7.8 (VDD); also elsewhere on the board
/AD8031_IN+: R9.1, R10.2, U6.3 (+IN)
/AD8031_IN-: R7.2, R8.1, U6.4 (-IN)
/AMP1_Out: C54.1, L3.1, U8.5 (RFOUT)
/AMP2_In: C2.2, U2.2 (RFIN)
/AMP2_Out: C1.1, L1.1, U2.5 (RFOUT)
/AMP3_Out: C22.1, L2.1, U5.5 (RFOUT)
/FL_Out: FL1.3 (Out), TP2.C (In)
/Mix_In: TP1.A (Out), U1.2 (IF)
/Mix_Out: FL1.1 (In), U1.4 (RF)
/PA_RF_IN: TP3.A (Out), U3.4 (RFIN)
/PLL_CE: J3.09; also elsewhere on the board
/PLL_CSB: J3.13; also elsewhere on the board
/PLL_Out: U5.2 (RFIN); also elsewhere on the board
/RF_In: J2.1, U8.2 (RFIN)
/RF_out: J1.1, U3.16 (RFOUT)
/SCK: J3.17, U7.1 (SCLK); also elsewhere on the board
/SDI: J3.20, U7.3 (DIN); also elsewhere on the board
/SDO: J3.19, U7.2 (DOUT); also elsewhere on the board
/TP1_In: C54.2, TP1.C (In)
/TP2_Out: C2.1, TP2.A (Out)
/TP3_In: C1.2, TP3.C (In)
/TP4_In: C22.2, TP4.C (In)
/T_CSB: J3.07, U7.4 (CS)
/Tx_LO: TP4.A (Out), U1.8 (LO)
/Tx_PM: J3.18, R8.2, U6.1 (VOUT)
/Vdd_AMP: C3.2, C4.2, C41.2, C42.2, C52.2, C53.2, J3.03, L1.2, L2.2, L3.2, R5.2, R6.2, U6.5 (+VS)
/Vdd_PA: C10.2, C11.2, C12.2, C18.2, C19.2, C20.2, C26.2, C27.2, C28.2, C34.2, C35.2, C36.2, J3.01, U3.11 (VDD4), U3.20 (VDD3), U3.21 (VDD2), U3.22 (VDD1)
/Vdet: R6.1, R7.1, U3.13 (VDET)
/Vg_PA1: C15.2, C16.2, C17.2, J3.06, U3.6 (VGG1)
/Vg_PA2: C23.2, C24.2, C25.2, J3.04, U3.7 (VGG2)
/Vg_PA3: C31.2, C32.2, C33.2, J3.02, U3.8 (VGG3)
/Vref: R5.1, R9.2, U3.12 (VREF)
GND: C3.1, C4.1, C10.1, C11.1, C12.1, C15.1, C16.1, C17.1, C18.1, C19.1, C20.1, C23.1, C24.1, C25.1, C26.1, C27.1, C28.1, C31.1, C32.1, C33.1, C34.1, C35.1, C36.1, C41.1, C42.1, C50.1, C52.1, C53.1, FL1.2 (GND), FL1.4 (GND), FL1.5 (GND), FL1.6 (GND), J1.2, J2.2, J3.05, J3.08, J3.10, J3.12, J3.14, J3.16, R10.1, SCRW1.1, SCRW2.1, SCRW3.1, SCRW4.1, TP1.G (GND), TP2.G (GND), TP3.G (GND), TP4.G (GND), U1.1 (GND), U1.3 (GND), U1.5 (GND), U1.6 (GND), U1.7 (GND), U1.9 (GND), U1.10 (GND), U2.1 (NIC_1), U2.3 (GND), U2.4 (NIC_2), U2.6 (NIC_3), U2.7 (EP), U3.1 (NC_1), U3.2 (NC_2), U3.3 (NC_3), U3.5 (GND_1), U3.9 (NC_4), U3.10 (NC_5), U3.14 (NC_6), U3.15 (GND_2), U3.17 (NC_7), U3.18 (NC_8), U3.19 (NC_9), U3.23 (NC_10), U3.24 (NC_11), U3.25 (THERMAL_PAD), U5.1 (NIC_1), U5.3 (GND), U5.4 (NIC_2), U5.6 (NIC_3), U5.7 (EP), U6.2 (-VS), U7.7 (GND), U7.9 (EP), U8.1 (NIC_1), U8.3 (GND), U8.4 (NIC_2), U8.6 (NIC_3), U8.7 (EP); also elsewhere on the board

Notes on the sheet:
LO Generation
Temperature and Transmitted Power
Power Amplifier
IC | V (V) | I (mA) | Power (mW) - - - - - - - - - - - - - - - - - - - PA | 6 | 1400 | ~2500 (class C) AMP1 | 5 | 76 | 380 AMP2 | 5 | 76 | 380 AMPLO | 5 | 76 | 380 PLL | 3.3 | 90 | 300 - - - - - - - - - - - - - - - - - - - Total | 4 W
Alternative 1
Screws
19-03-2022
Frequency Up-Conversion
XCOMMS_RF_v2
Connectors
Pre-Amplification 1
To do: Gruix Rogers R 0 Ohm
Pre-Amplification 2
Modifications: LO_EN eliminated -> PLL_CE
IC | V (V) | I (mA) | Power (mW) - - - - - - - - - - - - - - - - - - - PA | 5 | 1400 | ~2500 (class C) AMP1 | 4.5 | 65 | 290 AMP2 | 4.5 | 65 | 290 AMPLO | 4.5 | 65 | 290 PLL | 3.3 | 90 | 300 - - - - - - - - - - - - - - - - - - - Total | 3.7 W
Power Consumption Information

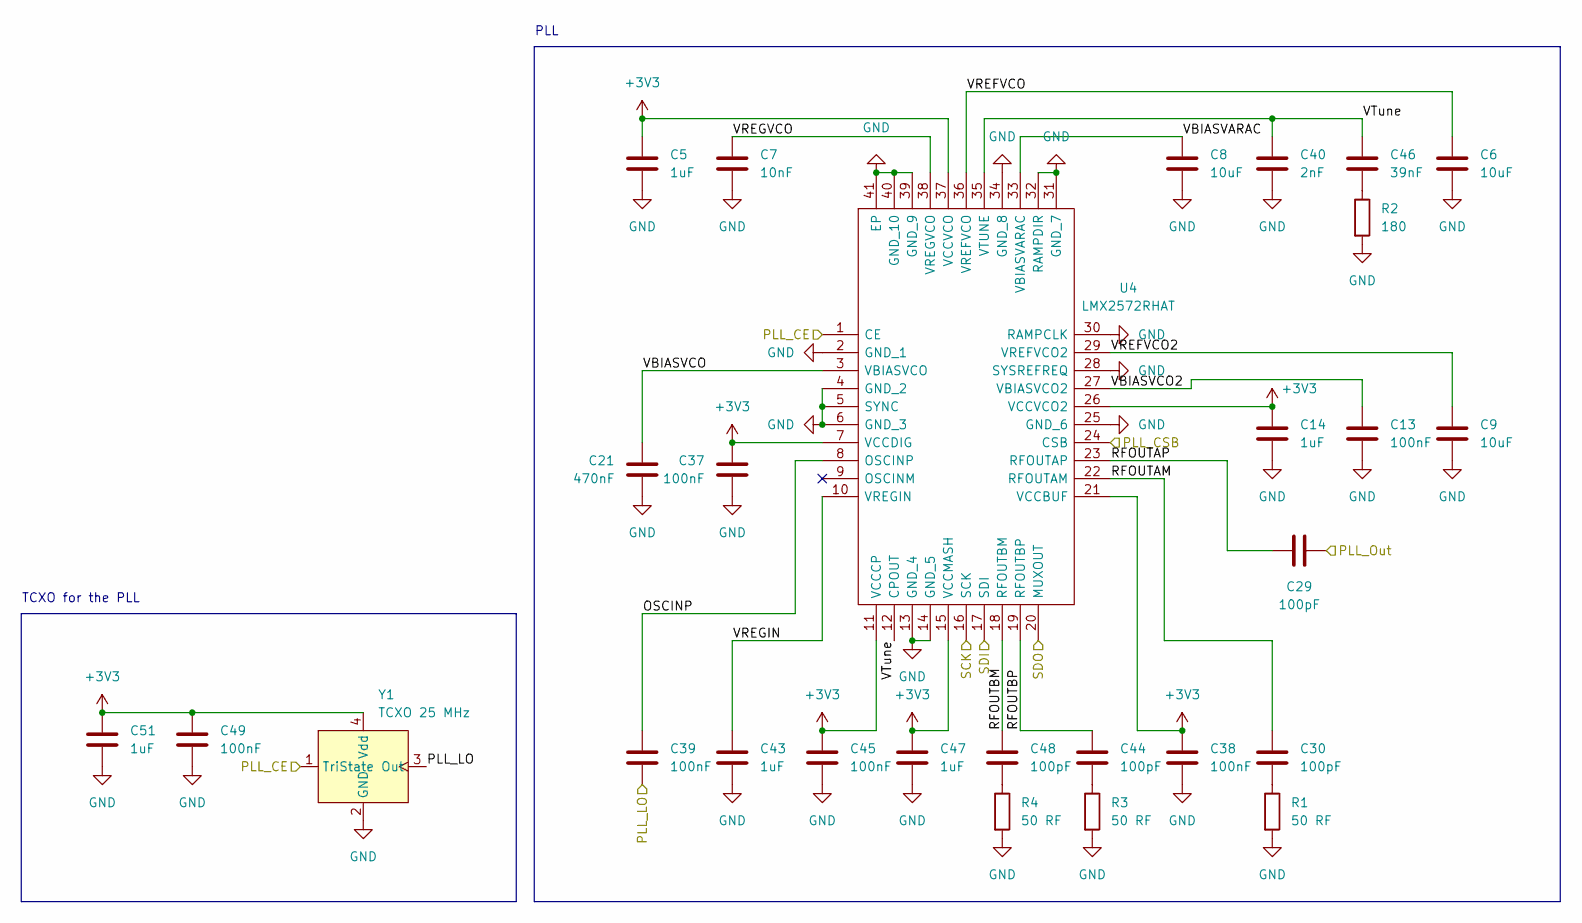
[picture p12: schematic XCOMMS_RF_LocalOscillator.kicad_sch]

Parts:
C5, C14, C43, C47, C51: 1uF; C_0603_1608Metric
C6, C8, C9: 10uF; C_0603_1608Metric
C7: 10nF; C_0603_1608Metric
C13, C37, C38, C39, C45, C49: 100nF; C_0603_1608Metric
C21: 470nF; C_0603_1608Metric
C29, C30, C44, C48: 100pF; C_0402_1005Metric
C40: 2nF; C_0603_1608Metric
C46: 39nF; C_0603_1608Metric
R1, R3, R4: 50 RF; R_0402_1005Metric
R2: 180; R_0603_1608Metric
U4: LMX2572RHAT; QFN50P600X600X100-41N-D; Mouser Part Number 595-LMX2572RHAT
Y1: TCXO 25 MHz; TCXO_ECS

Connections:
+3V3: C5.2, C14.2, C37.2, C38.2, C45.2, C47.2, C49.1, C51.2, U4.7 (VCCDIG), U4.11 (VCCCP), U4.15 (VCCMASH), U4.21 (VCCBUF), U4.26 (VCCVCO2), U4.37 (VCCVCO), Y1.4 (Vdd); also elsewhere on the board
/LocalOscillator/OSCINP: C39.2, U4.8 (OSCINP)
/LocalOscillator/RFOUTAM: C30.2, U4.22 (RFOUTAM)
/LocalOscillator/RFOUTAP: C29.1, U4.23 (RFOUTAP)
/LocalOscillator/RFOUTBM: C48.2, U4.18 (RFOUTBM)
/LocalOscillator/RFOUTBP: C44.2, U4.19 (RFOUTBP)
/LocalOscillator/VBIASVARAC: C8.2, U4.33 (VBIASVARAC)
/LocalOscillator/VBIASVCO: C21.2, U4.3 (VBIASVCO)
/LocalOscillator/VBIASVCO2: C13.2, U4.27 (VBIASVCO2)
/LocalOscillator/VREFVCO: C6.2, U4.36 (VREFVCO)
/LocalOscillator/VREFVCO2: C9.2, U4.29 (VREFVCO2)
/LocalOscillator/VREGIN: C43.2, U4.10 (VREGIN)
/LocalOscillator/VREGVCO: C7.2, U4.38 (VREGVCO)
/LocalOscillator/VTune: C40.2, C46.2, U4.12 (CPOUT), U4.35 (VTUNE)
/PLL_CE: U4.1 (CE), Y1.1 (TriState); also elsewhere on the board
/PLL_CSB: U4.24 (CSB); also elsewhere on the board
/PLL_LO: C39.1, Y1.3 (Out)
/PLL_Out: C29.2; also elsewhere on the board
/SCK: U4.16 (SCK); also elsewhere on the board
/SDI: U4.17 (SDI); also elsewhere on the board
/SDO: U4.20 (MUXOUT); also elsewhere on the board
GND: C5.1, C6.1, C7.1, C8.1, C9.1, C13.1, C14.1, C21.1, C37.1, C38.1, C40.1, C43.1, C45.1, C47.1, C49.2, C51.1, R1.2, R2.2, R3.2, R4.2, U4.2 (GND_1), U4.4 (GND_2), U4.5 (SYNC), U4.6 (GND_3), U4.13 (GND_4), U4.14 (GND_5), U4.25 (GND_6), U4.28 (SYSREFREQ), U4.30 (RAMPCLK), U4.31 (GND_7), U4.32 (RAMPDIR), U4.34 (GND_8), U4.39 (GND_9), U4.40 (GND_10), U4.41 (EP), Y1.2 (GND); also elsewhere on the board
unnamed: C30.1, R1.1
unnamed: C44.1, R3.1
unnamed: C46.1, R2.1
unnamed: C48.1, R4.1

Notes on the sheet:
TCXO for the PLL
PLL

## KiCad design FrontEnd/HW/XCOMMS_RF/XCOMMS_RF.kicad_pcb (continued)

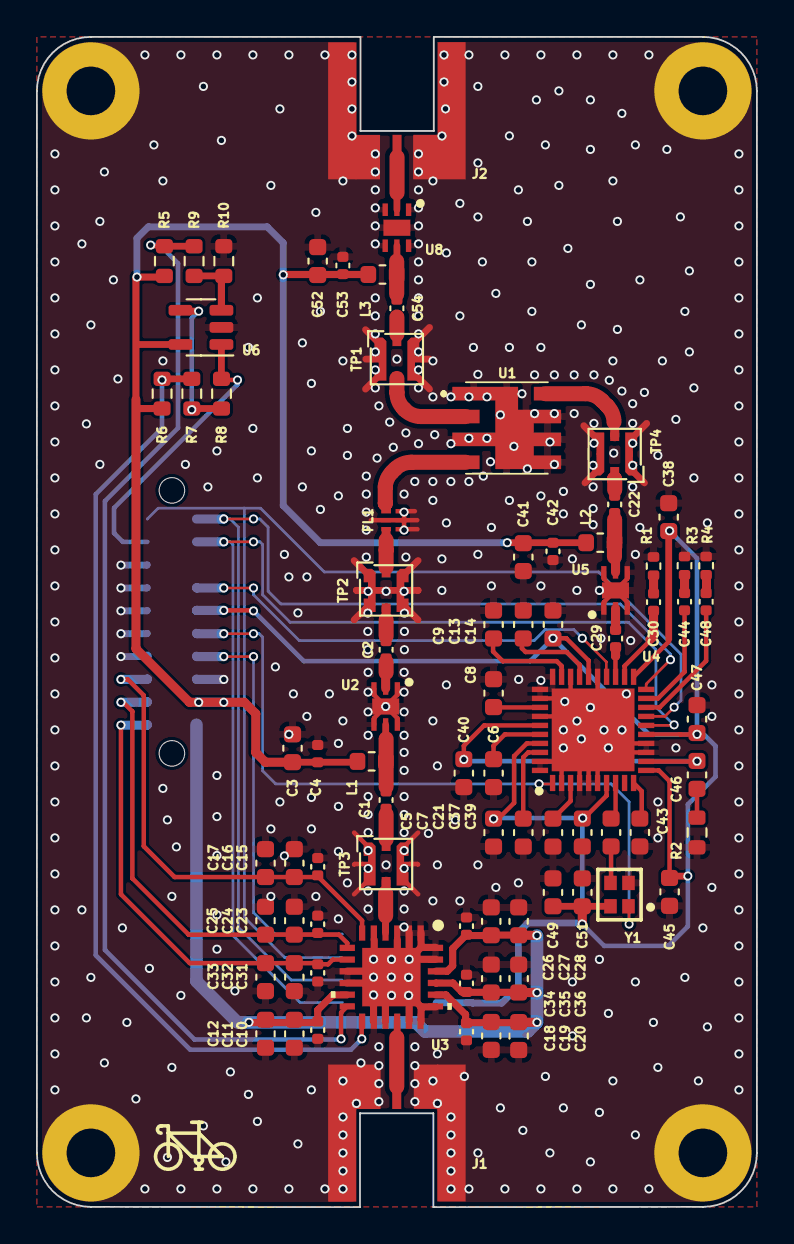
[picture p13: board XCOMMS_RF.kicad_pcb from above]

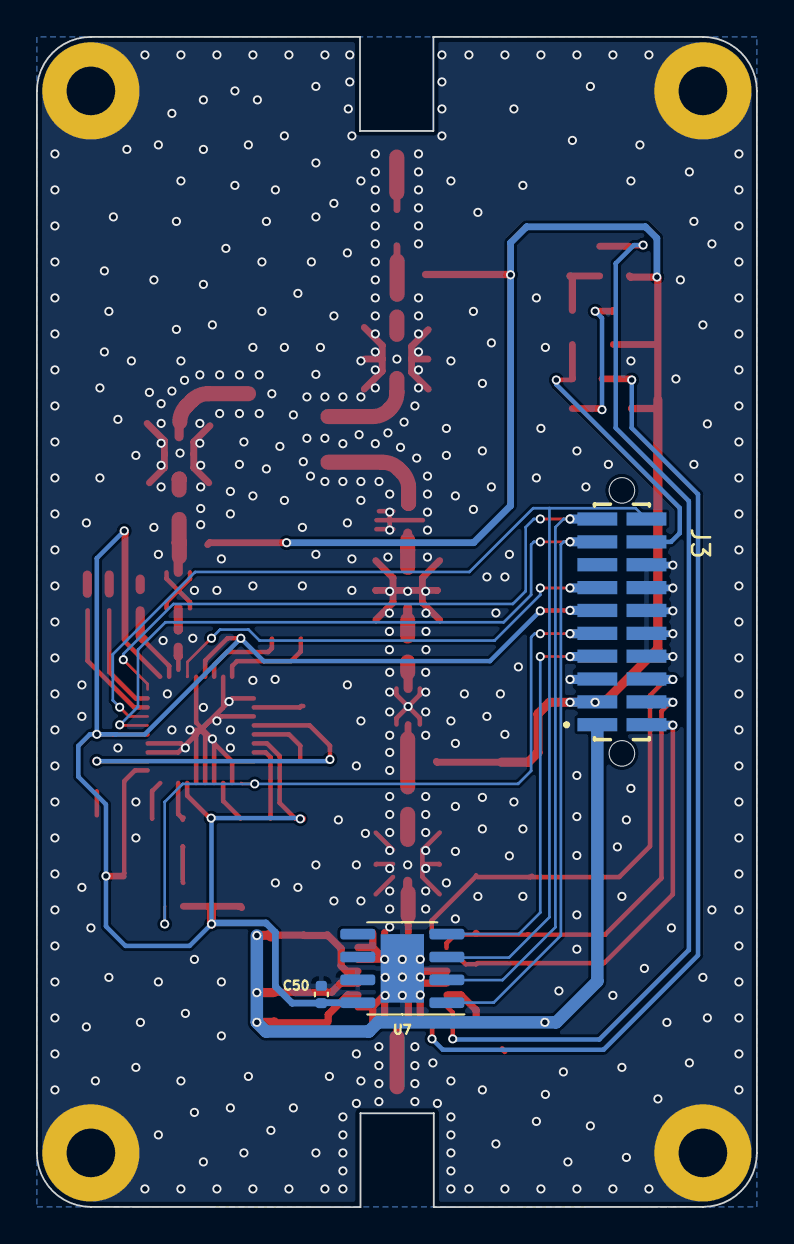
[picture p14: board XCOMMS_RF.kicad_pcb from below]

Board: 2 copper layers, 40.0 x 65.0 mm, 88 parts (3 on the bottom side), 52 nets.

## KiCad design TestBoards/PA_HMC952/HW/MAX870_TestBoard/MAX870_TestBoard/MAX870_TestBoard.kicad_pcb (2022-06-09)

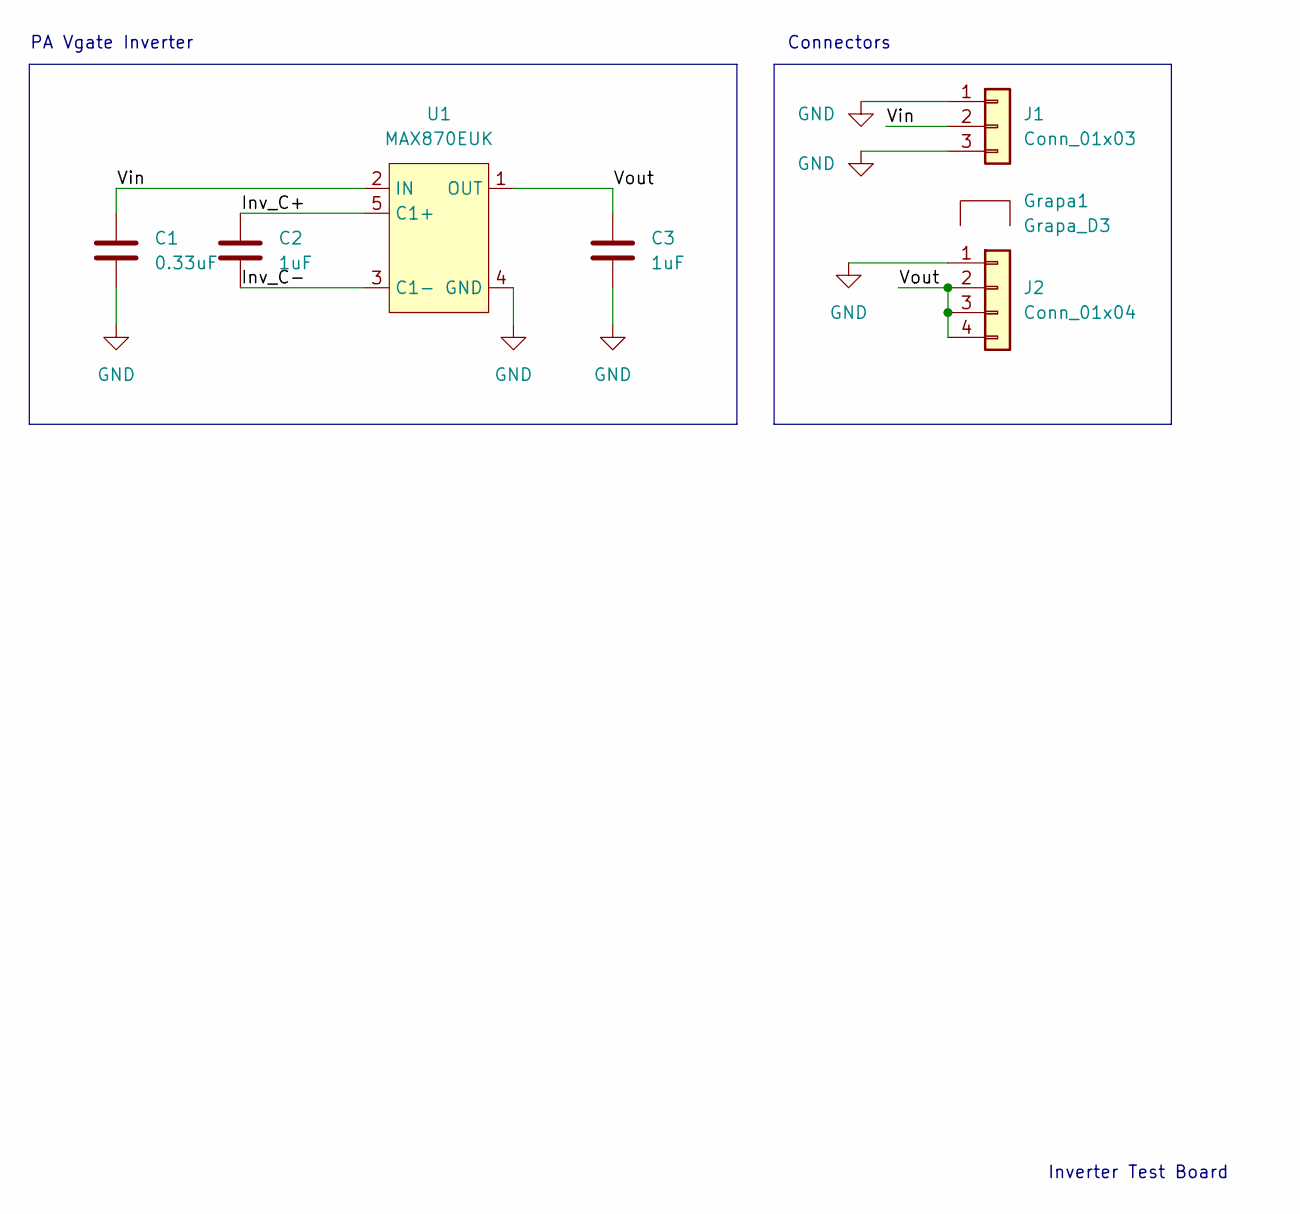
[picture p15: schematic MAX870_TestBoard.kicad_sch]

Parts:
C1: 0.33uF; C_0603_1608Metric
C2, C3: 1uF; C_0603_1608Metric
Grapa1: Grapa_D3; Grapa_0.8mm_11.9mm
J1: Conn_01x03; PinHeader_1x03_P2.54mm_Vertical
J2: Conn_01x04; PinHeader_1x04_P2.54mm_Vertical
U1: MAX870EUK; SOT-23-5

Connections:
/Inv_C+: C2.2, U1.5 (C1+)
/Inv_C-: C2.1, U1.3 (C1-)
/Vin: C1.2, J1.2, U1.2 (IN)
/Vout: C3.2, J2.2, J2.3, J2.4, U1.1 (OUT)
GND: C1.1, C3.1, J1.1, J1.3, J2.1, U1.4 (GND)

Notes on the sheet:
PA Vgate Inverter
Connectors
Inverter Test Board

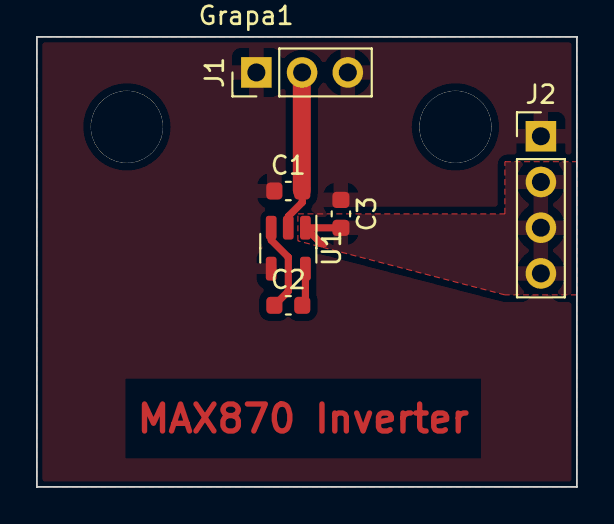
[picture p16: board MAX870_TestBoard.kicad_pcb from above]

Board: 2 copper layers, 30.0 x 25.0 mm, 7 parts (0 on the bottom side), 5 nets.

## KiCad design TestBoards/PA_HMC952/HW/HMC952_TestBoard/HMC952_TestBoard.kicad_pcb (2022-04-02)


Board: 2 copper layers, 50.0 x 40.0 mm, 30 parts (0 on the bottom side), 9 nets.

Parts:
C1, C2, C3, C10, C11, C12, C13: 100pF; C_0402_1005Metric
C4, C5, C6, C14, C15, C16, C17: 10nF; C_0603_1608Metric
C7, C8, C9, C18, C19, C20, C21: 4.7uF; C_0805_2012Metric
J1, J2: SMA; LINX_CONSMA020.062-G
J3, J4, J5: Conn_01x04; PinHeader_1x04_P2.54mm_Vertical
SCRW1, SCRW2, SCRW3: MountingHole_Pad; MountingHole_2.7mm_M2.5_ISO14580
U1: HMC952ALP5GE; QFN65P500X500X100-25N-D

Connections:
/RF_In: J1.1 (RF), U1.4 (RFIN)
/RF_out: J2.1 (RF), U1.16 (RFOUT)
/Vd_PA: C10.2, C11.2, C12.2, C13.2, C14.2, C15.2, C16.2, C17.2, C18.2, C19.2, C20.2, C21.2, J3.1, J3.2, U1.11 (VDD4), U1.20 (VDD3), U1.21 (VDD2), U1.22 (VDD1)
/Vdet: J5.1, U1.13 (VDET)
/Vg_PA1: C1.2, C4.2, C7.2, J4.2, U1.6 (VGG1)
/Vg_PA2: C2.2, C5.2, C8.2, J4.3, U1.7 (VGG2)
/Vg_PA3: C3.2, C6.2, C9.2, J4.4, U1.8 (VGG3)
/Vref: J5.3, U1.12 (VREF)
GND: C1.1, C2.1, C3.1, C4.1, C5.1, C6.1, C7.1, C8.1, C9.1, C10.1, C11.1, C12.1, C13.1, C14.1, C15.1, C16.1, C17.1, C18.1, C19.1, C20.1, C21.1, J1.S1, J1.S2, J1.S3, J1.S4, J2.S1, J2.S2, J2.S3, J2.S4, J3.3, J3.4, J4.1, J5.2, J5.4, U1.1 (NC_1), U1.2 (NC_2), U1.3 (NC_3), U1.5 (GND_1), U1.9 (NC_4), U1.10 (NC_5), U1.14 (NC_6), U1.15 (GND_2), U1.17 (NC_7), U1.18 (NC_8), U1.19 (NC_9), U1.23 (NC_10), U1.24 (NC_11), U1.25 (THERMAL_PAD)

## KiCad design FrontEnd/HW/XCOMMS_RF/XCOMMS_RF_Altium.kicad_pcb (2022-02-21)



Board: 2 copper layers, 40.0 x 65.0 mm, 82 parts (3 on the bottom side), 51 nets.

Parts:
C1, C2, C4, C10, C15, C18, C22, C23, C26, C29, C30, C31, C34, C42, C44, C48: Cap Semi; 0402 SND CAPACITOR
C3, C5, C7, C11, C13, C14, C16, C19, C24, C27, C32, C35, C37, C38, C39, C41, C43, C45, C47, C49, C50, C51: Cap Semi; 0603 SMD Capacitor
C6, C8, C9, C12, C17, C20, C21, C25, C28, C33, C36, C40, C46: Cap Semi; 0805 SMD Capacitor
FL1: NotchFilter; Notch_5600to6100MHz
J1, J2: SMA; CONSMA020-062-G
J3: SFC-110-T2-F-D-A-TR; SAMTEC_SFC-110-T2-F-D-A-TR
L1, L2: Inductor; 0603 SMD Inductor
R1, R3, R4: Res3; 0402 SMD Resistor
R2, R5, R6, R7, R8, R9, R10: Res3; 0603 SMD Resistor
SCRW1, SCRW2, SCRW3, SCRW4: Metric Screw Hole; M3 ScrewHole
TP1, TP2, TP3: MSC-156C; MS-156C
U1: SIM-14+; HV1195_Minicircuits
U2, U5: HMC788A
U3: HMC952ALP5GE; CP_24_20_ADI
U4: LMX2572; QFN50P600X600X100-41N
U6: AD8031; SOT-23-5
U7: ADT7310; SOIC-8
Y1: TCXO 25 MHz; ECS-TXO-2016

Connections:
3V3: C5.2, C14.1, C38.1, C45.1, C49.1, C50.2, C51.2, J3.02, U4.11, U4.21, U4.26, U4.37, U7.8, Y1.4
5V: C3.2, C4.2, C41.2, C42.2, J3.01, L1.2, L2.2, R5.2, R6.2, U6.5
GND: C3.1, C4.1, C5.1, C6.2, C7.1, C8.2, C9.1, C10.2, C11.2, C12.2, C13.1, C14.2, C15.2, C16.2, C17.2, C18.2, C19.2, C20.2, C21.1, C23.2, C24.2, C25.2, C26.2, C27.2, C28.2, C31.2, C32.2, C33.2, C34.2, C35.2, C36.2, C37.2, C38.2, C40.1, C41.1, C42.1, C43.1, C45.2, C47.1, C49.2, C50.1, C51.1, J1.2, J1.3, J1.4, J1.5, J2.2, J2.3, J2.4, J2.5, J3.06, J3.08, J3.10, J3.11, J3.12, J3.13, R1.1, R2.2, R3.1, R4.1, R10.2, SCRW1.1, SCRW2.1, SCRW3.1, SCRW4.1, TP1.3, TP1.4, TP2.3, TP2.4, TP3.3, TP3.4, U1.1, U1.3, U1.5, U1.6, U1.7, U2.1, U2.3, U2.4, U2.6, U3.1, U3.2, U3.3, U3.5, U3.9, U3.10, U3.14, U3.15, U3.17, U3.18, U3.19, U3.23, U3.24, U3.25, U4.2, U4.4, U4.5, U4.6, U4.13, U4.14, U4.25, U4.28, U4.30, U4.31, U4.32, U4.34, U4.39, U4.40, U4.41, U5.1, U5.3, U5.4, U5.6, U6.2, U7.7, Y1.2
LO_EN: J3.05, Y1.1
NetC1_1: C1.1, L1.1, U2.5
NetC1_2: C1.2, TP2.1
NetC2_1: C2.1, TP1.2
NetC2_2: C2.2, U2.2
NetC6_1: C6.1, U4.36
NetC7_2: C7.2, U4.38
NetC8_1: C8.1, U4.33
NetC9_2: C9.2, U4.29
NetC13_2: C13.2, U4.27
NetC21_2: C21.2, U4.3
NetC22_1: C22.1, L2.1, U5.5
NetC22_2: C22.2, TP3.1
NetC29_1: C29.1, U4.23
NetC29_2: C29.2, U5.2
NetC30_1: C30.1, U4.22
NetC30_2: C30.2, R1.2
NetC37_1: C37.1, U4.7
NetC39_2: C39.2, U4.8
NetC40_2: C40.2, C46.2, U4.12, U4.35
NetC43_2: C43.2, U4.10
NetC44_1: C44.1, U4.19
NetC44_2: C44.2, R3.2
NetC46_1: C46.1, R2.1
NetC47_2: C47.2, U4.15
NetC48_1: C48.1, R4.2
NetC48_2: C48.2, U4.18
NetFL1_1: FL1.1, TP1.1, U1.4
NetR7_1: R7.1, R8.2, U6.4
NetR9_1: R9.1, R10.1, U6.3
PA_RF_IN: TP2.2, U3.4
PLL_CSB: J3.14, U4.24
PLL_LO: C39.1, Y1.3
RF_Tx_in: J1.1, U1.2
RF_Tx_out: J2.1, U3.16
SCK: J3.15, U4.16, U7.1
SDI: J3.19, U4.17, U7.3
SDO: J3.17, U4.20, U7.2
T_CSB: J3.07, U7.4
Tx_CE: J3.09, U4.1
Tx_LO: TP3.2, U1.8
Tx_PM: J3.04, R8.1, U6.1
Vd_PA: C10.1, C11.1, C12.1, C18.1, C19.1, C20.1, C26.1, C27.1, C28.1, C34.1, C35.1, C36.1, J3.03, U3.11, U3.20, U3.21, U3.22
Vdet: R6.1, R7.2, U3.13
Vg_PA1: C15.1, C16.1, C17.1, J3.20, U3.6
Vg_PA2: C23.1, C24.1, C25.1, J3.18, U3.7
Vg_PA3: C31.1, C32.1, C33.1, J3.16, U3.8
Vref: R5.1, R9.2, U3.12

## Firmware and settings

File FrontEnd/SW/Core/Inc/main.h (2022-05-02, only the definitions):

#define Pout_PA_Pin GPIO_PIN_1
#define Pout_PA_GPIO_Port GPIOA
#define Id_PA_Pin GPIO_PIN_2
#define Id_PA_GPIO_Port GPIOA
#define EN_6V_Pin GPIO_PIN_0
#define EN_6V_GPIO_Port GPIOB
#define EN_5V_Pin GPIO_PIN_1
#define EN_5V_GPIO_Port GPIOB
#define T_CSB_Pin GPIO_PIN_3
#define T_CSB_GPIO_Port GPIOB
#define PLL_CE_Pin GPIO_PIN_4
#define PLL_CE_GPIO_Port GPIOB
#define PLL_CSB_Pin GPIO_PIN_5
#define PLL_CSB_GPIO_Port GPIOB

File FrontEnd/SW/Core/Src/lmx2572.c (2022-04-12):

/* 	*************** README *************
 * 	This driver includes the needed register programming for using the PLL of the LMX2572,
 * 	some configurations have not been implemented since from default are deactivated.
 *
 * 	Implemented: User control registers, PLL, VCO Partial Assist, outputs, CPG
 *
 * 	To implement: FSK, Ramping, Burst Mode, SYSREF Divider, MASH and Phase Synchronization
 *
 * 	************************************
 */

#include "lmx2572.h"

// Determine N, NUM and DEN values from target frequency
void LMX2572_det_param(struct PLL pll){
	pll.fpd = pll.Fosc * pll.osc_2x * pll.pll_r_pre * pll.pll_r * pll.mult;
	pll.pll_n = pll.frequency/pll.fpd;
	pll.pll_den = 1000;
	pll.pll_num = (pll.frequency/pll.fpd-pll.pll_n)*pll.pll_den;
	pll.Fvco = pll.fpd * pll.pll_n + (pll.pll_num * pll.fpd / pll.pll_den);
}

// Writes a register to the PLL
void LMX2572_write(struct PLL pll, SPI_HandleTypeDef *hspi, uint32_t value) {
	uint8_t spi_buf[3] = {0,0,0};
	uint8_t port;
	uint8_t pin = pll.pin;
	spi_buf[2] = value;
	spi_buf[1] = value >> 8;
	spi_buf[0] = value >> 16;

	HAL_GPIO_WritePin(&port, &pin, GPIO_PIN_RESET);	// CSB LOW
	HAL_SPI_Transmit(hspi, spi_buf, 3, 100);
	HAL_GPIO_WritePin(pll.port, pll.pin, GPIO_PIN_SET);		// CSB HIGH
}

// Reads a register value from the PLL
uint32_t LMX2572_read(struct PLL pll, SPI_HandleTypeDef *hspi, uint32_t value) {
	uint32_t read = 0;
	uint8_t read_value[2] = {0x00, 0x00};
	uint8_t spi_buf[3] = {0,0,0};
	spi_buf[2] = value | (1<<7);
	spi_buf[1] = value >> 8;
	spi_buf[0] = value >> 16;

	HAL_GPIO_WritePin(pll.port, pll.pin, GPIO_PIN_RESET);	// CSB LOW
	HAL_SPI_Transmit(hspi, spi_buf, 3, 100);
	HAL_SPI_Receive(hspi, read_value, 2, 10);
	HAL_GPIO_WritePin(pll.port, pll.pin, GPIO_PIN_SET);		// CSB HIGH

	read += read_value[0];
	read += read_value[1] >> 8;
	return read;
}

// Loads the registers to the PLL
void LMX2572_load_regs(struct PLL pll, SPI_HandleTypeDef *hspi){
	int i = 0;
	while ((pll.R[125-i] & 0x00FF0000) != 0) {
		LMX2572_write(pll, hspi, pll.R[125-i]);
		i++;
	}
	LMX2572_write(pll, hspi, pll.R[125-i]);
}

// Resets the PLL
// Works
void LMX2572_reset(struct PLL pll, SPI_HandleTypeDef *hspi){
	uint8_t spi_buf[3] = {0,0,0};
	spi_buf[2] = 0x1E;
	spi_buf[1] = 0x21;
	spi_buf[0] = 0x00;

	HAL_GPIO_WritePin(&pll.port, &pll.pin, GPIO_PIN_RESET);	// CSB LOW
	HAL_SPI_Transmit(hspi, spi_buf, 3, 100);
	HAL_GPIO_WritePin(&pll.port, &pll.pin, GPIO_PIN_SET);	// CSB LOW

	HAL_Delay(500);
}

// Powers Down the PLL
void LMX2572_off_PLL(struct PLL pll, SPI_HandleTypeDef *hspi){
	pll.R[0] |= (0x01 << 0);

	uint8_t spi_buf[3] = {0,0,0};
	spi_buf[2] = pll.R[0];
	spi_buf[1] = pll.R[0] >> 8;
	spi_buf[0] = pll.R[0] >> 16;

	HAL_GPIO_WritePin(pll.port, pll.pin, GPIO_PIN_RESET);	// CSB LOW
	HAL_SPI_Transmit(hspi, spi_buf, 3, 100);
	HAL_GPIO_WritePin(pll.port, pll.pin, GPIO_PIN_SET);		// CSB HIGH
}

// Powers Up the PLL
void LMX2572_on_PLL(struct PLL pll, SPI_HandleTypeDef *hspi){
	pll.R[0] &= ~(0x01 << 0);

	uint8_t spi_buf[3] = {0,0,0};
	spi_buf[2] = pll.R[0];
	spi_buf[1] = pll.R[0] >> 8;
	spi_buf[0] = pll.R[0] >> 16;

	HAL_GPIO_WritePin(pll.port, pll.pin, GPIO_PIN_RESET);	// CSB LOW
	HAL_SPI_Transmit(hspi, spi_buf, 3, 100);
	HAL_GPIO_WritePin(pll.port, pll.pin, GPIO_PIN_SET);		// CSB HIGH
}

// Loads PLL default registers to the register bank
// Works
void LMX2572_default(struct PLL pll, uint32_t lmx2572Regs[]){
	for(int i=0; i<126; i++){
		pll.R[i] = lmx2572Regs[125-i];
	}
}

// Inits LMX2572
void LMX2572_init(struct PLL pll, uint32_t lmx2572Regs[]) {
	HAL_GPIO_WritePin(pll.port, pll.pin, GPIO_PIN_SET);		// CSB HIGH
	LMX2572_default(pll, lmx2572Regs);
	LMX2572_det_param(pll);

	pll.R[44] |= (0x01 << 6);
	pll.R[44] |= (0x01 << 7);
}

// Sets Charge Pump Gain in uA
void LMX2572_set_cpg(struct PLL pll) {
	pll.R[14] &= 0xFF1800;
	if (pll.CPG == 0) 			pll.R[14] |= 0x0000;		// CPG = 0
	else if (pll.CPG == 625) 	pll.R[14] |= 0x0008;		// CPG = 1
	else if (pll.CPG == 1250) 	pll.R[14] |= 0x0010;		// CPG = 2
	else if (pll.CPG == 1875) 	pll.R[14] |= 0x0018;		// CPG = 3
	else if (pll.CPG == 2500) 	pll.R[14] |= 0x0020;		// CPG = 4
	else if (pll.CPG == 3125) 	pll.R[14] |= 0x0028;		// CPG = 5
	else if (pll.CPG == 3750) 	pll.R[14] |= 0x0030;		// CPG = 6
	else if (pll.CPG == 4375) 	pll.R[14] |= 0x0038;		// CPG = 7
	else if (pll.CPG == 5000) 	pll.R[14] |= 0x0060;		// CPG = 12
	else if (pll.CPG == 5625) 	pll.R[14] |= 0x0068;		// CPG = 13
	else if (pll.CPG == 6250) 	pll.R[14] |= 0x0070;		// CPG = 14
	else if (pll.CPG == 6875) 	pll.R[14] |= 0x0078;		// CPG = 15
}

// Sets pfd
void LMX2572_set_fpd(struct PLL pll) {
	// Set Doubler
	if (pll.osc_2x == 2) pll.R[9] |= (0x01 << 12);
	else 			 	 pll.R[9] &= ~(0x01 << 12);

	// Set Pre R
	pll.R[12] &= ~(0xFFF << 0);
	pll.R[12] |= ((pll.pll_r_pre & 0xFFF) << 0);

	// Set Multiplier
	pll.R[10] &= ~(0x1F << 7);
	pll.R[10] |= ((pll.mult & 0x1F) << 7);

	// Set R
	pll.R[11] &= ~(0xFF << 4);
	pll.R[11] |= ((pll.pll_r & 0xFF) << 4);

	if (pll.Fosc * pll.osc_2x * pll.pll_r_pre * pll.mult > 100) pll.R[9] |= (0x01 << 14);
	else pll.R[9] &= ~(0x01 << 14);
}

// Set PLL N, DEN and NUM
// Works
void LMX2572_set_PLL(struct PLL pll) {
	pll.R[34] &= ~(0x07 << 0);
	pll.R[34] |= (((pll.pll_n >> 16) & 0x07) << 0);
	pll.R[36] &= ~(0xFFFF << 0);
	pll.R[36] |= ((pll.pll_n & 0xFFFF) << 0);

	pll.R[38] &= ~(0xFFFF << 0);
	pll.R[38] |= ((pll.pll_den >> 16) << 0);
	pll.R[39] &= ~(0xFFFF << 0);
	pll.R[39] |= ((pll.pll_den & 0x0000FFFF) << 0);

	pll.R[42] &= ~(0xFFFF << 0);
	pll.R[42] |= ((pll.pll_num >> 16) << 0);
	pll.R[43] &= ~(0xFFFF << 0);
	pll.R[43] |= ((pll.pll_num & 0x0000FFFF) << 0);
}
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

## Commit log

2021-11-26 added PA test board folder
2022-02-05 started translating altium to kicad
2022-02-05 Altium2Kicad translation
    [1510641002.stp, FSI-110-03-G-D-AD.stp, FSI-110-10-L-D-AD.stp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]
2022-02-16 Altium to KiCad translation of interface board
    [Coilcraft-XAL6060.STEP, ECS-TXO-2016-33-250-TR.STEP, HCP_6_1_ADI.step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]
2022-02-16 Interface board modified
    [XCOMMS_Interface.csv, XCOMMS_Interface.kicad_pcb]
2022-02-21 RF frontend translated to Kicad from Altium
    [XCOMMS_RF.kicad_pcb, XCOMMS_RF.kicad_sch, XCOMMS_RF_Altium.kicad_pcb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]
2022-02-21 XCOMMS_RF and XCOMMS_Interface KiCad design updated
    [XCOMMS_Interface.kicad_pcb, XCOMMS_Interface.kicad_sch, XCOMMS_PowerSupply.kicad_sch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]
2022-02-22 XCOMMS_RF ported to KiCad
    [XCOMMS_RF.kicad_pcb, XCOMMS_RF.kicad_sch, XCOMMS_RF_LocalOscillator.kicad_sch]
2022-02-25 XCOMS_RF updated
    [XCOMMS_RF.kicad_pcb, XCOMMS_RF.kicad_sch, XCOMMS_RF_LocalOscillator.kicad_sch]
2022-03-08 XCOMMS_RF update
    [HMC952_TestBoard.kicad_pcb, HMC952_TestBoard.kicad_sch, XCOMMS_RF.kicad_pcb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]
2022-03-10 Relaxed Design RUles and output files generated
    [XCOMMS_RF-B_Cu.gbl, XCOMMS_RF-B_Silkscreen.gbo, XCOMMS_RF-F_Cu.gtl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]
2022-03-10 HMC592 TB Schematic
    [HMC952_TestBoard.kicad_sch]
2022-03-18 PA TB
    [HMC952_TestBoard.kicad_pcb, XCOMMS_RF.kicad_pcb, XCOMMS_RF.kicad_sch]
2022-03-21 XCOMMS RF update and PA EvalBoard
    [1211-66139-TD--3DModel-STEP-216184.STEP, HMC952_TestBoard.kicad_pcb, HMC952_TestBoard.kicad_sch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]
2022-03-22 XCOMMS RF update
    [XCOMMS_RF.kicad_sch]
2022-04-07 XCOMMS Interface rebuild
    [HMC952_TestBoard_RO4003C_60mils.kicad_pcb, XCOMMS_Interface.kicad_pcb, XCOMMS_Interface.kicad_sch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]
2022-04-07 xtal changed and routing
    [XCOMMS_Interface.kicad_pcb, XCOMMS_Interface.kicad_sch, XCOMMS_RF.kicad_sch]
2022-04-12 redundant MCU
    [XCOMMS_Interface.kicad_pcb, XCOMMS_Interface.kicad_sch]
2022-04-12 starting redundant mcu
    [XCOMMS_Interface.kicad_pcb, XCOMMS_Interface.kicad_sch]
2022-04-12 continuation of previous
    [XCOMMS_Interface.kicad_pcb, XCOMMS_Interface.kicad_sch]
2022-05-02 XCOMMS RF
    [1211-66139-TD--3DModel-STEP-216184.STEP, 1510641002.stp, Coilcraft-XAL6060.STEP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]
2022-05-11 simplified PA gate control
    [XCOMMS_Interface.kicad_pcb, XCOMMS_Interface.kicad_sch, XCOMMS_PowerSupply.kicad_sch]
2022-05-13 PA gate control updated and Inverter
    [MAX870_TestBoard.kicad_pcb, MAX870_TestBoard.kicad_sch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]
2022-06-09 don't remember
    [MAX870_TestBoard.kicad_pcb, XCOMMS_EGSE.kicad_pcb, XCOMMS_EGSE.kicad_sch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]
2022-06-10 shield started
    [Part17.SLDPRT, XCOMMS_Assembly.SLDASM, XCOMMS_RF.kicad_pcb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]

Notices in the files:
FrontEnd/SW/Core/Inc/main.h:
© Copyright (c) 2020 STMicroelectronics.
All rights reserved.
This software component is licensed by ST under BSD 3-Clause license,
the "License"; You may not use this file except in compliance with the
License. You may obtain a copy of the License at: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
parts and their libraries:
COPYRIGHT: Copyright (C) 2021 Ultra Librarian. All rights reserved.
